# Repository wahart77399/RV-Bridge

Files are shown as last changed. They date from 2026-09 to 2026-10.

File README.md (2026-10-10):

# SmartCoach (aka RV-Bridge): HomeKit to RV-C Adapter 
This is a forked version of Randy Ubillos's RV-Bridge

## Overview
### Credit and Origin
The RV-Bridge was originally developed by Randy Ubillos, you may find the original documentation from him, here at https://github.com/rubillos/RV-Bridge. After reviewing his code, I felt it needed significant work to make it more modular and Object Oriented and less monolithic. I forked from his GitHub and re-architected the design.

## Development and Hardware
Originally, I used Randy’s original hardware and 3D casing. Unfortunately, the ESP32 board he used did not allow me to build all the devices I wanted. So, I researched and found a different board, the ESP32-S3 with CAN and LIN bus connections from SKPang. You can find the board [here](https://copperhilltech.com/esp32s3-can-lin-bus-board/). Once I made that decision, I decided to add more capability, including:
* Captive Portal for setting up Wifi Credentials
* Device Creation from JSON file
* Coach Specification Creation from JSON file
* Auto Discovery of devices
* Web Portal
     * Learning / listening of devices on RVC CAN bus.
     * Coach Spec editing
     * Name assignment and enabling of devices
     * Listening of CAN bus for unassigned devices
     * CAN bus diagnostics
     * Reboot of SmartCoach
     * Automatic email diagnostic and device reports
     * Wipe Wifi Credentials
 
These capabilities add substantial features making it more of a SmartCoach solution and not just a simple bridge.
For email relay setup, see [the guide](cloud/gmail-relay/README.md).
In addition, I've upgraded the library stack to be current with HomeSpan and uses the internal TWAI on the ESP32. Finally, I added regression test suite for the builds.

---
## Sample EVE Home Screens
These screenshots show RV devices in the EVE Home app, including awning, motion, and door-lock controls. The available screens depend on the devices installed in the coach.

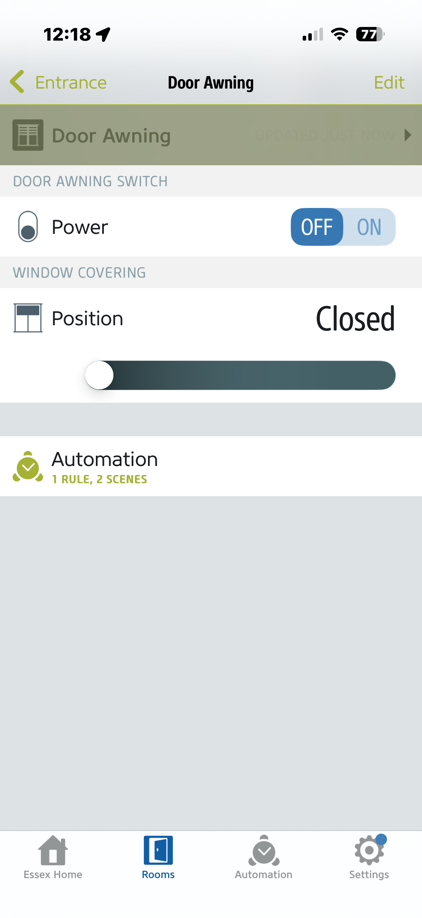
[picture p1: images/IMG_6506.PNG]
Door awning and window covering controls
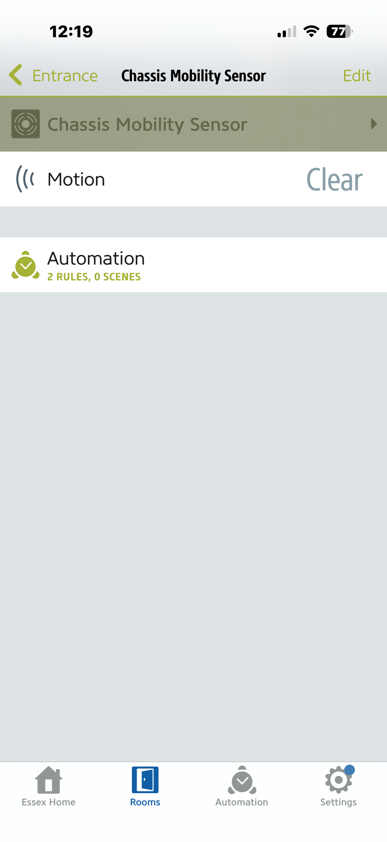
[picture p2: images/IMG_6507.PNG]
Chassis motion sensor status
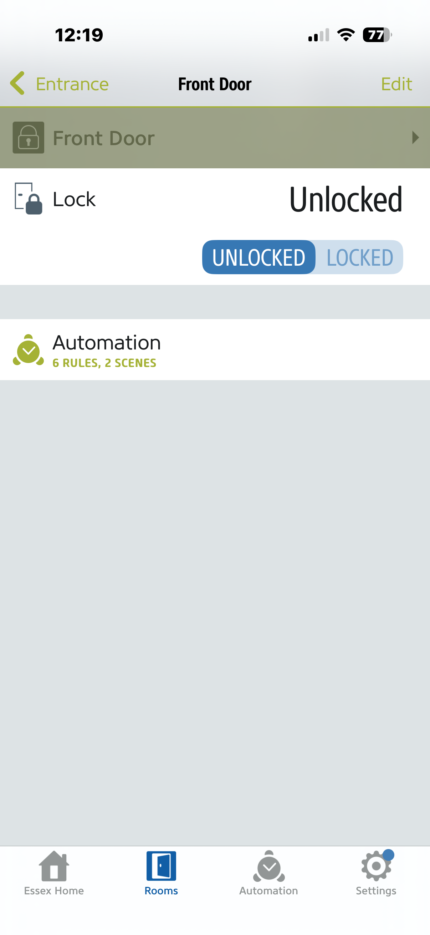
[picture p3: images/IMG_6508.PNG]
Front door lock controls
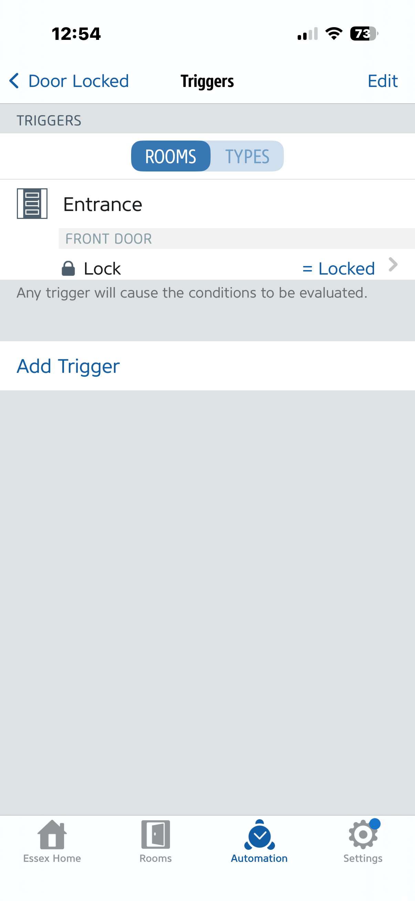
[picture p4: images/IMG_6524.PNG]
          |  
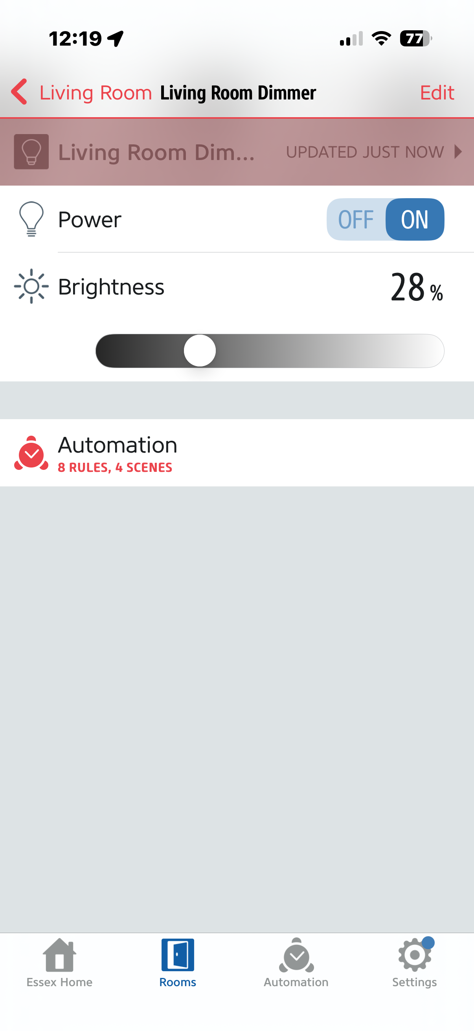
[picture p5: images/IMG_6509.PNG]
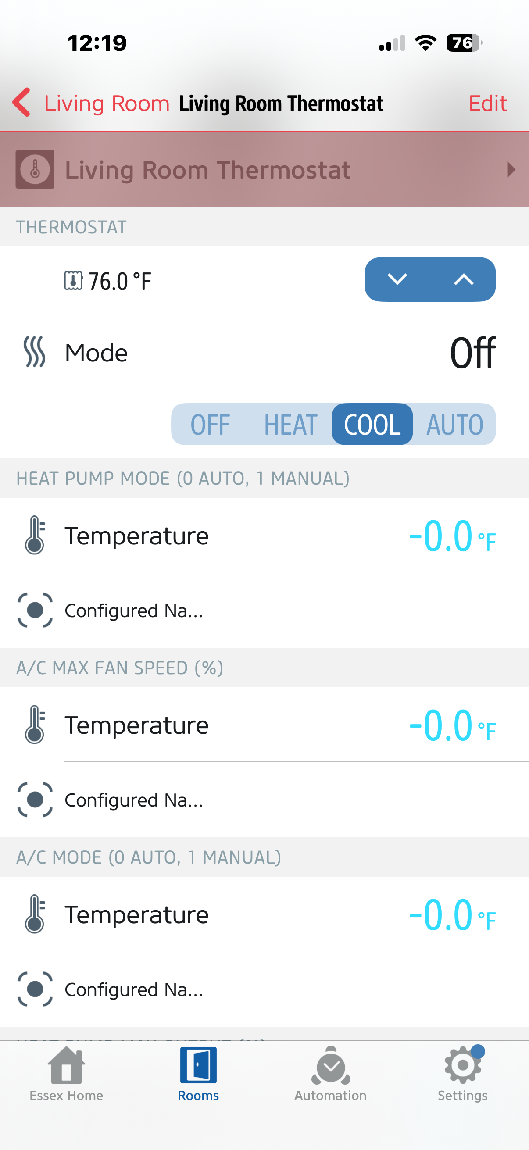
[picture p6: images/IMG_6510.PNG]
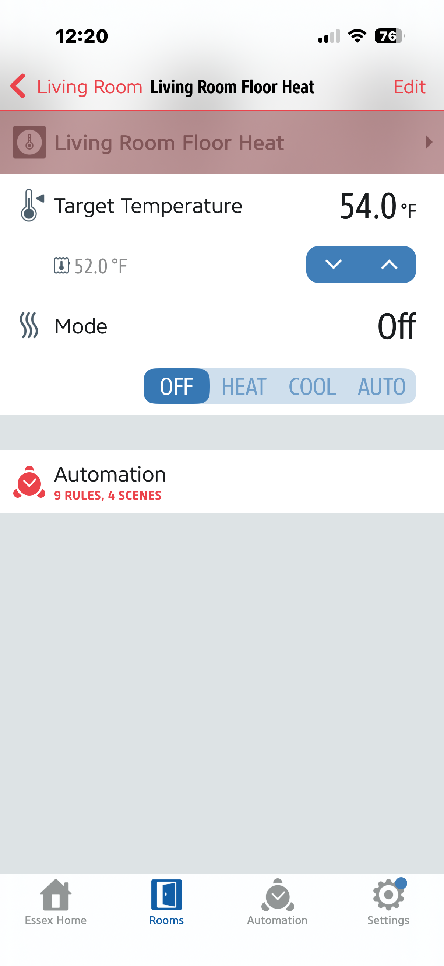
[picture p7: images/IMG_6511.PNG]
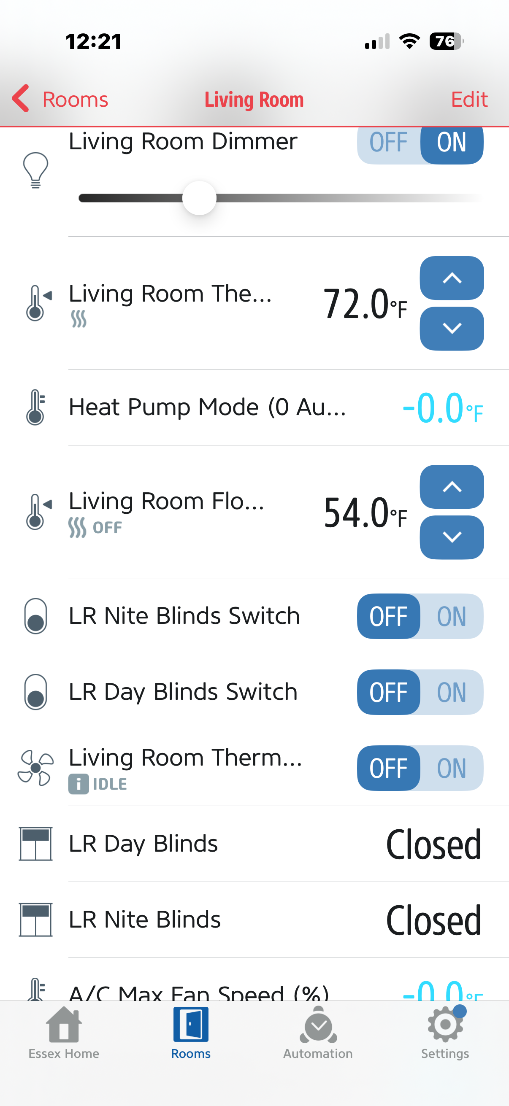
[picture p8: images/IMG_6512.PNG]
          |  

---
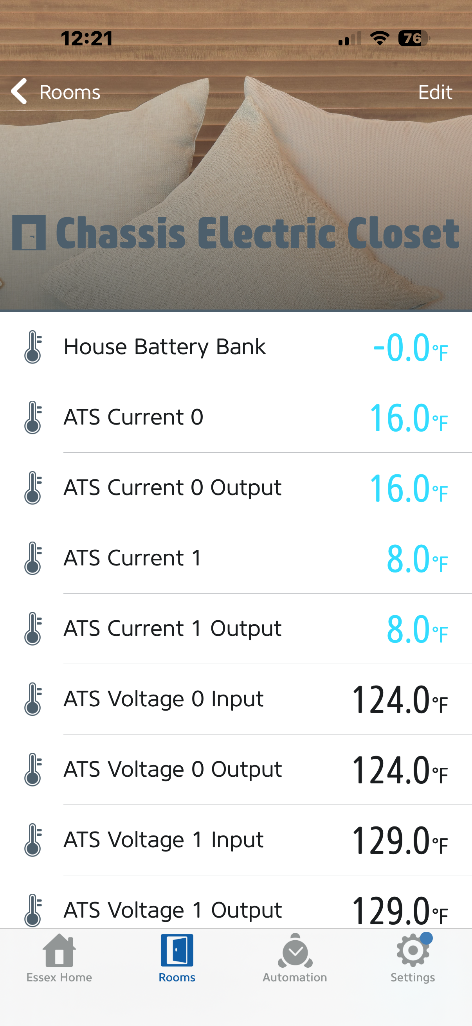
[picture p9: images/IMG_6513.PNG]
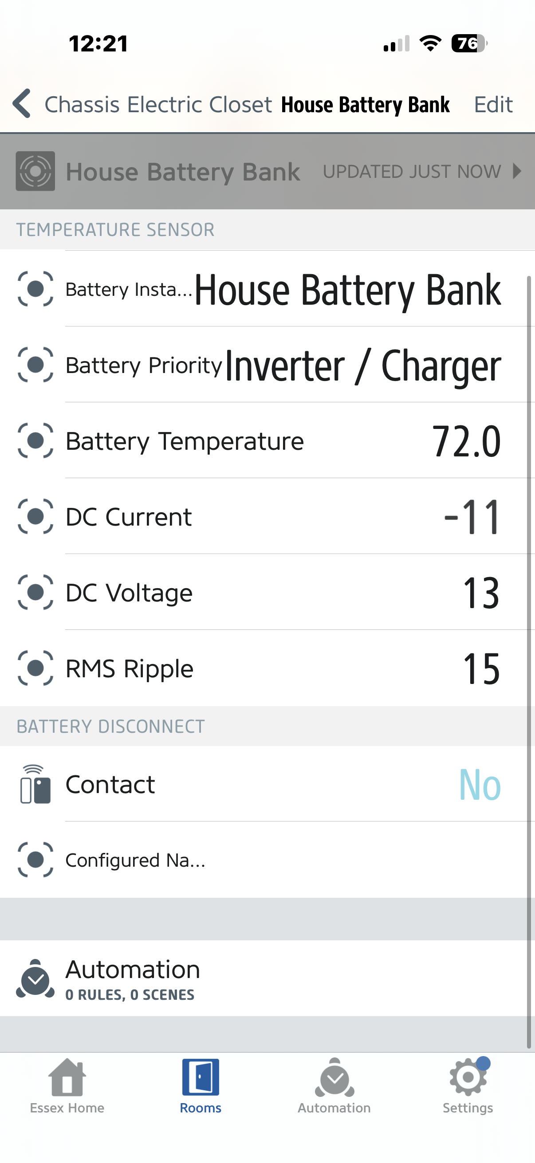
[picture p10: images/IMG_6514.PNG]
    
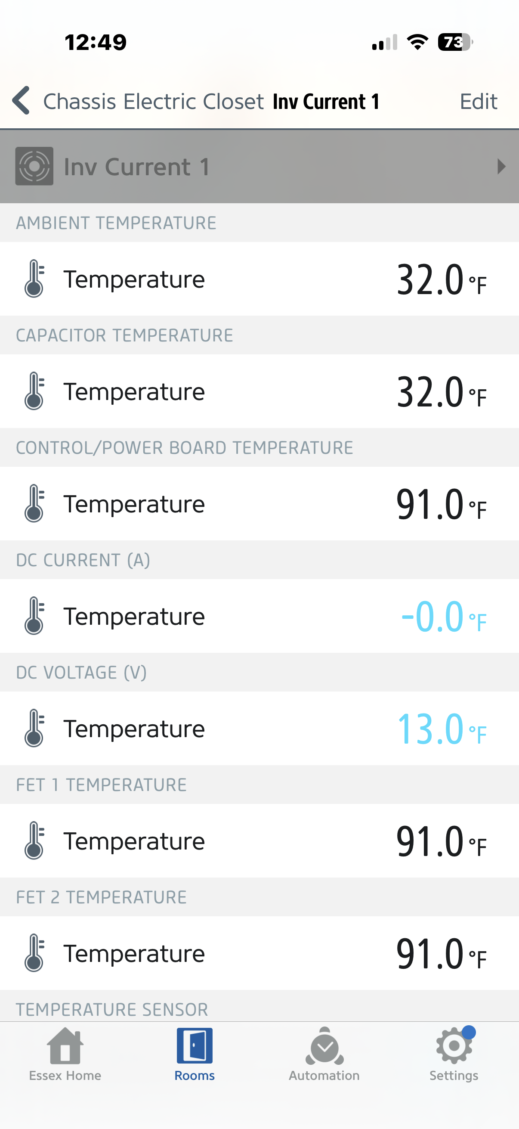
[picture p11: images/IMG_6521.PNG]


---
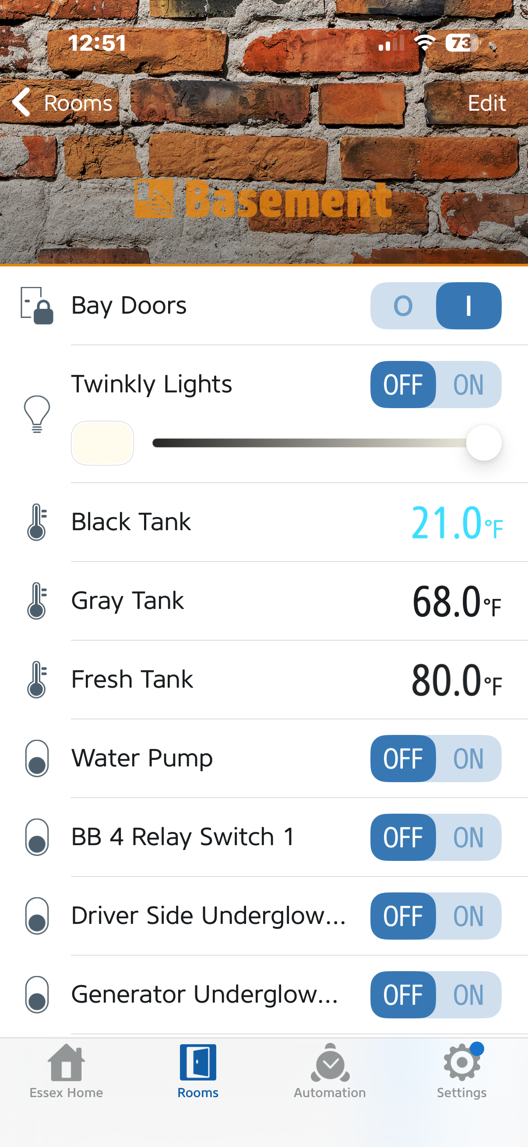
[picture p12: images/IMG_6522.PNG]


---
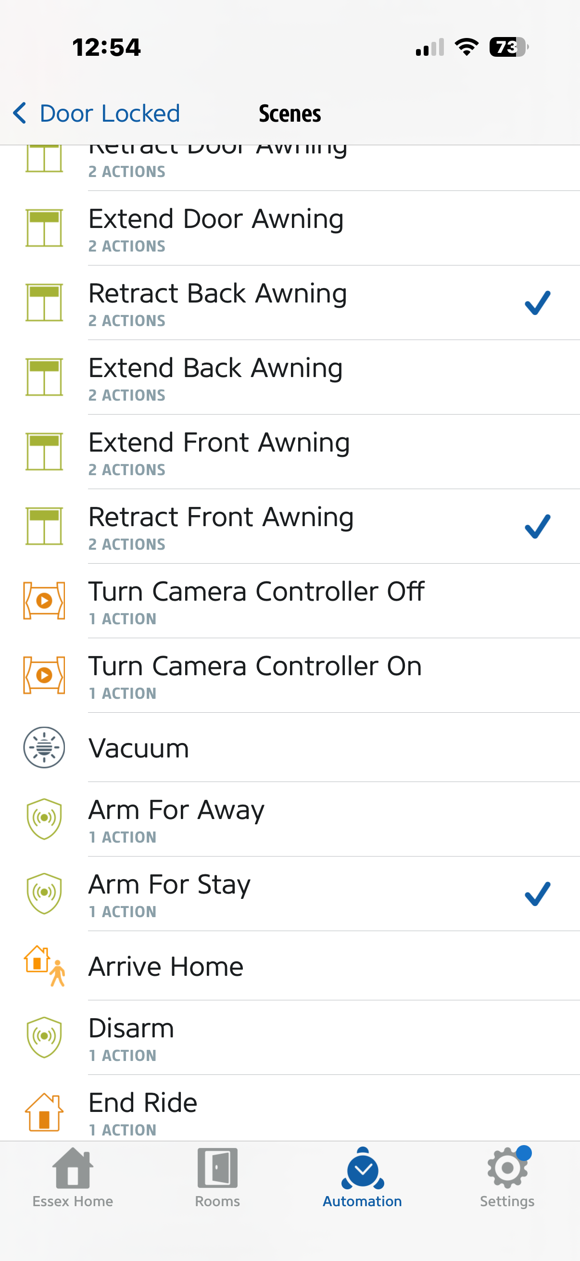
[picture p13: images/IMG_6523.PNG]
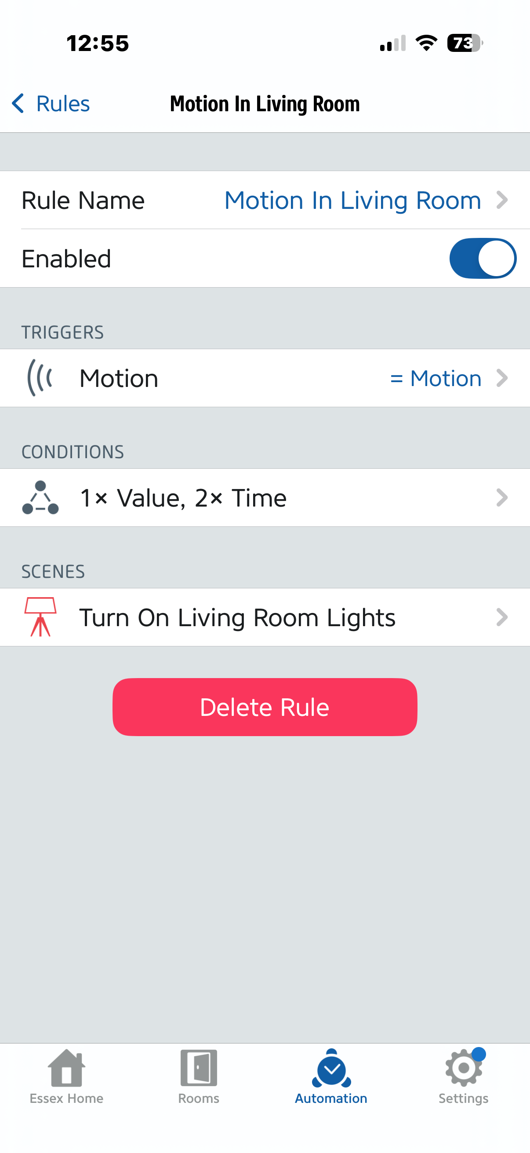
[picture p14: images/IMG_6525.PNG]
  

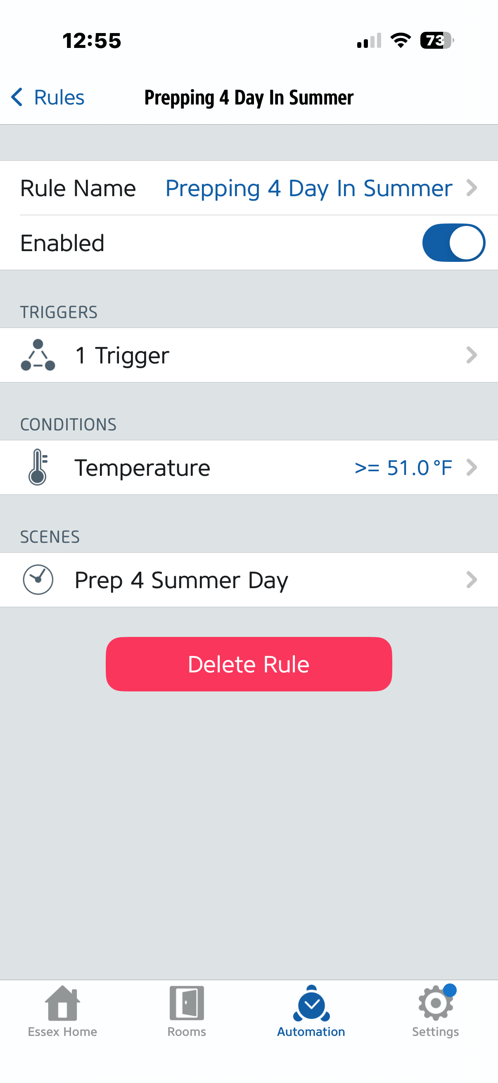
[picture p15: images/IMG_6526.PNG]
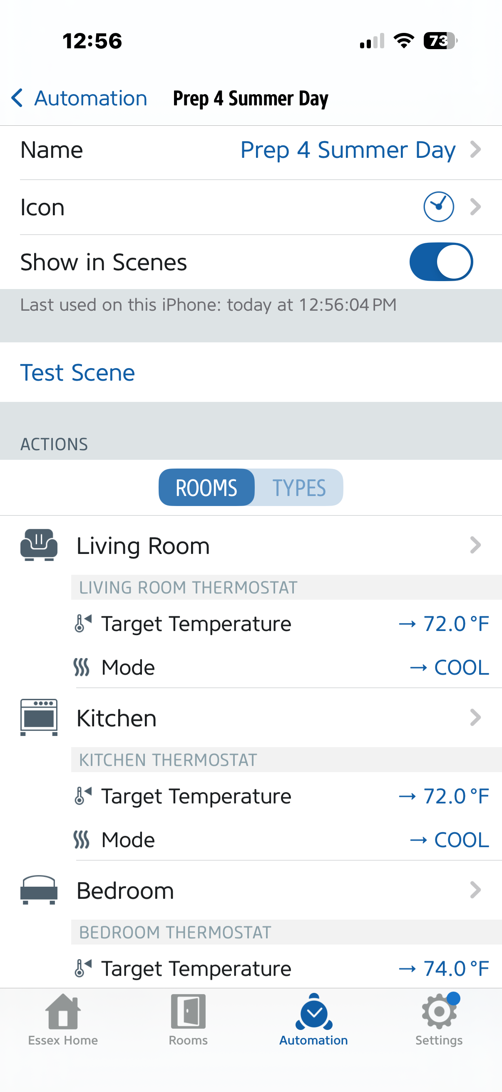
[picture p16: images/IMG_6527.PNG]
  

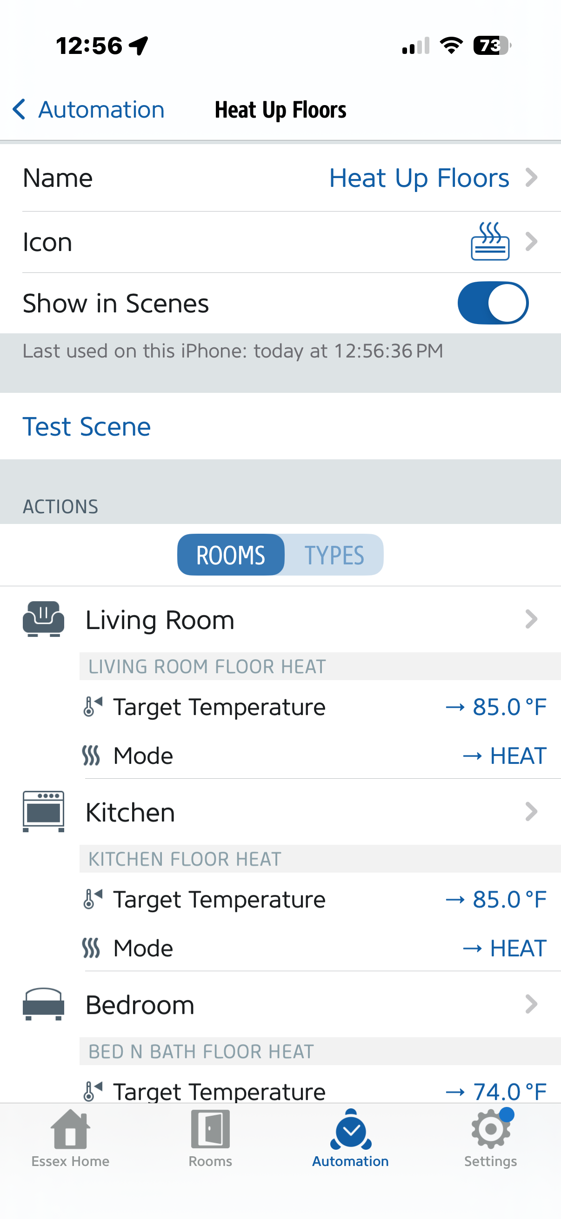
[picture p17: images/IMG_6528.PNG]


## Web Portal
The first screen shows the coach profile and discovered devices.
The upper-right menu provides live Status, Diagnostics, Email Reports, Email setup, and the Privacy Notice. System actions are separated in the menu; Wi-Fi reset and reboot require confirmation. Status refreshes from the bridge's routine status poll without running a discovery scan.

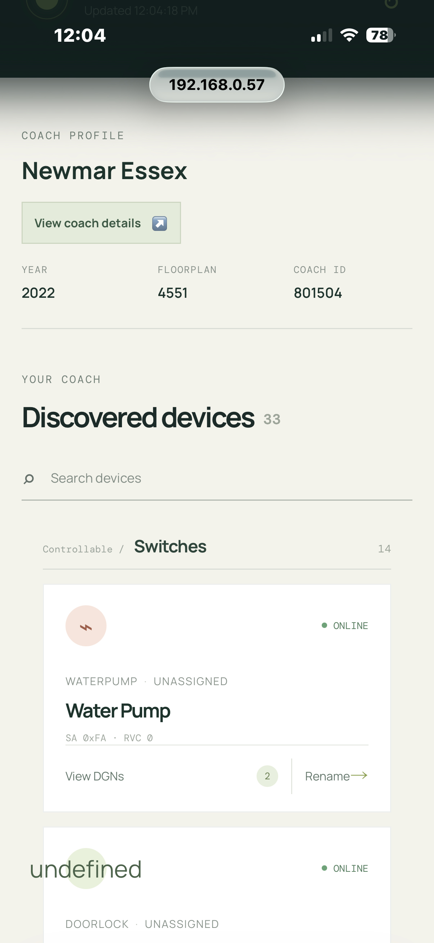
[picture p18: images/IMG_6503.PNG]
Web Portal Top of Page


---
This screenshot, below, shows the coach details when you click on the "View Coach Details" button at the top.

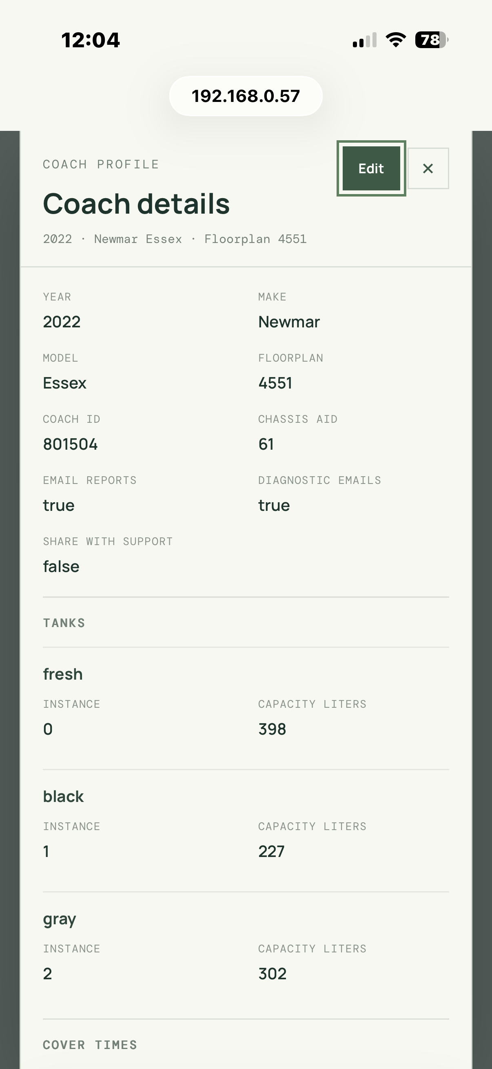
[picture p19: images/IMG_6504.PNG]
Coach Details


---
This Water Pump has been discovered but is still unassigned. Its card shows the two related RV-C messages.

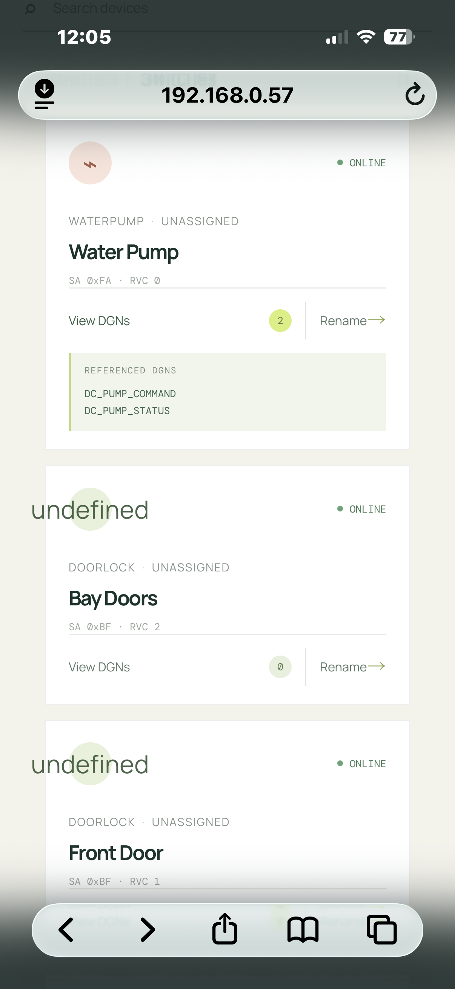
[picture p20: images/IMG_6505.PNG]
Unassigned Water Pump card showing its RV-C messages


---
This screenshot shows an earlier footer layout. The current portal places these tools and system actions in the upper-right menu.

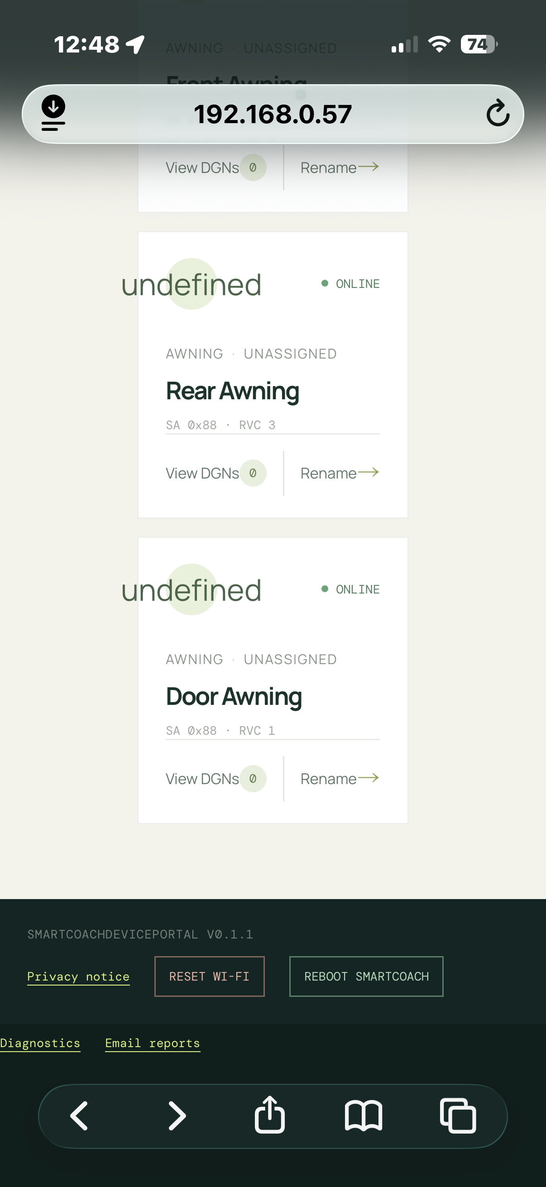
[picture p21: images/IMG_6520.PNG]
Diagnostic Page Bottom


### Diagnostic Portal
The diagnostics page shows bridge health, configured devices, and unmapped CAN traffic.

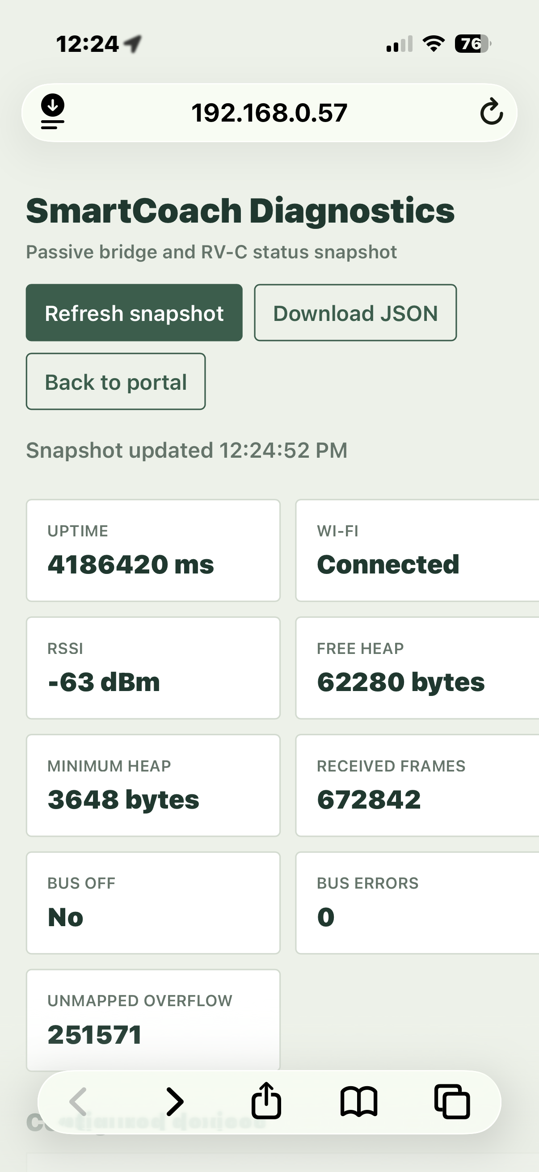
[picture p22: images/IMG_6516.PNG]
Diagnostics Page Top
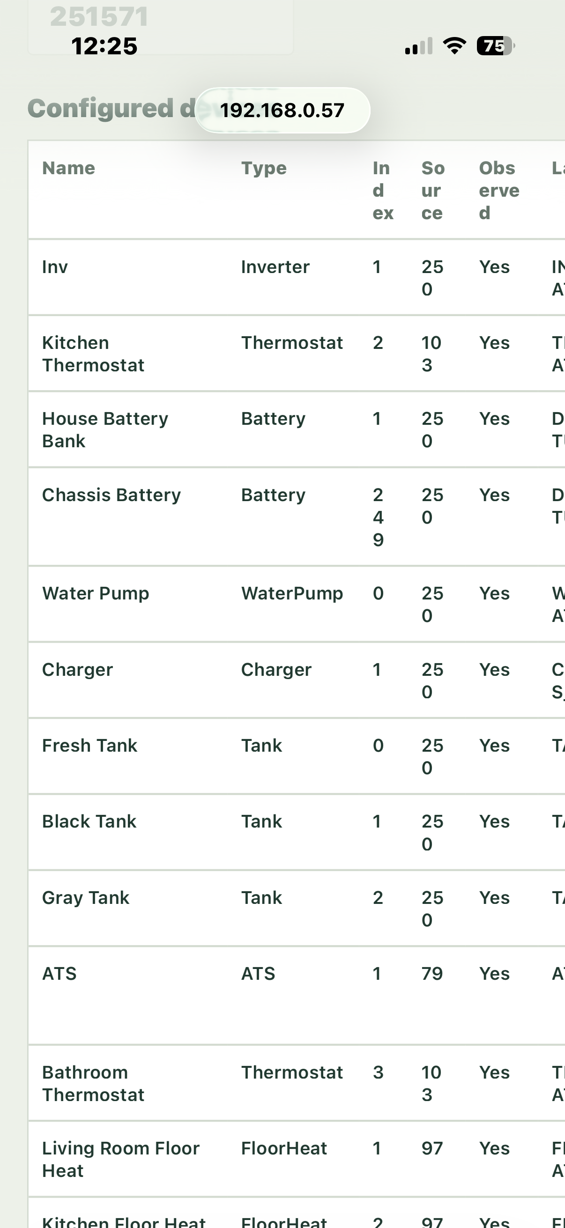
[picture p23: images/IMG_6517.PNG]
Diagnostics Page Showing Configured Device Metrics
   

---
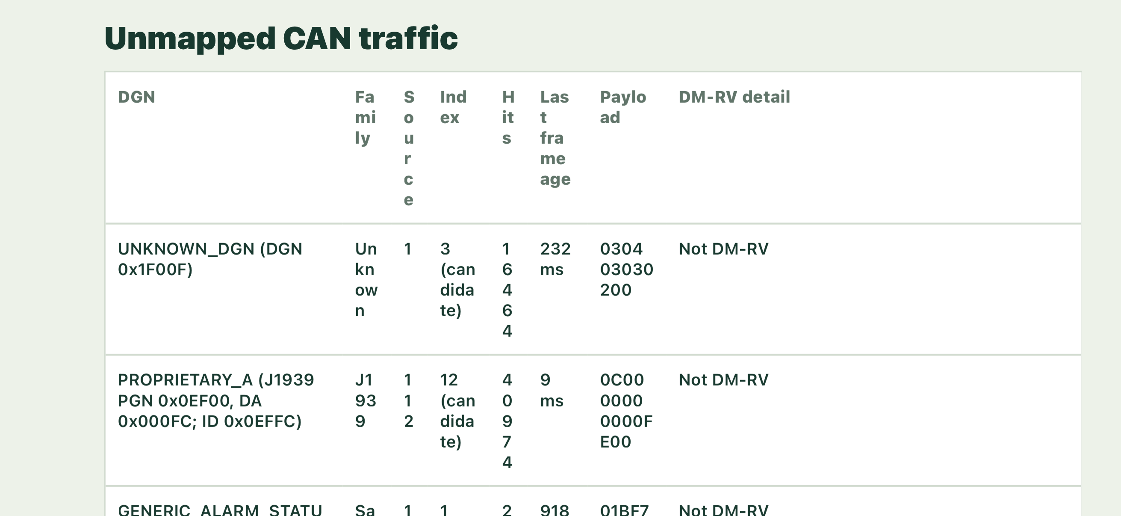
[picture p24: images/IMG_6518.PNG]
Diagnostics table showing unmapped CAN messages

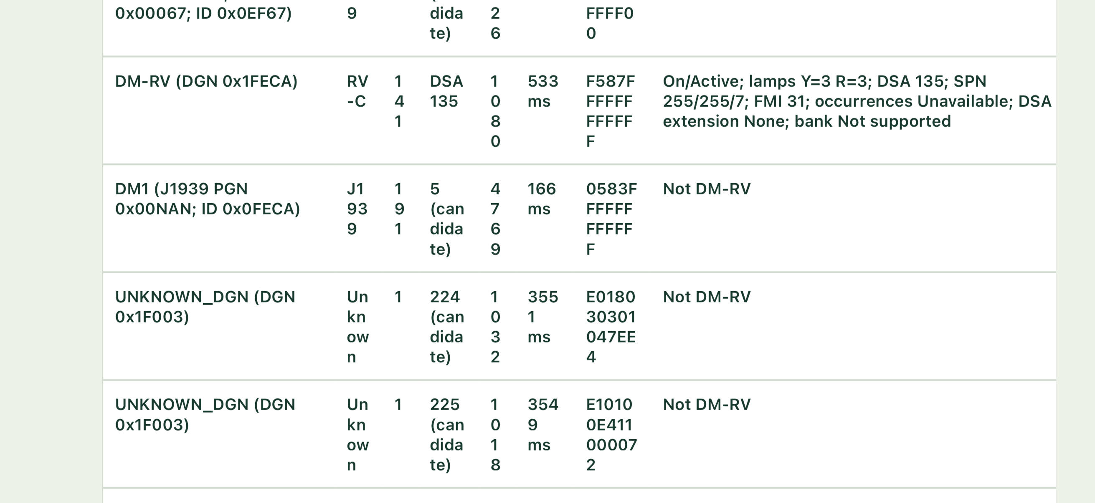
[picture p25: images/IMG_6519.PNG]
Diagnostics table showing decoded DM-RV details


### Email Portal
The email page lets owners choose report options and configure email delivery.

## Captive Portal
The captive portal collects coach Wi-Fi, coach details, and report preferences during setup.
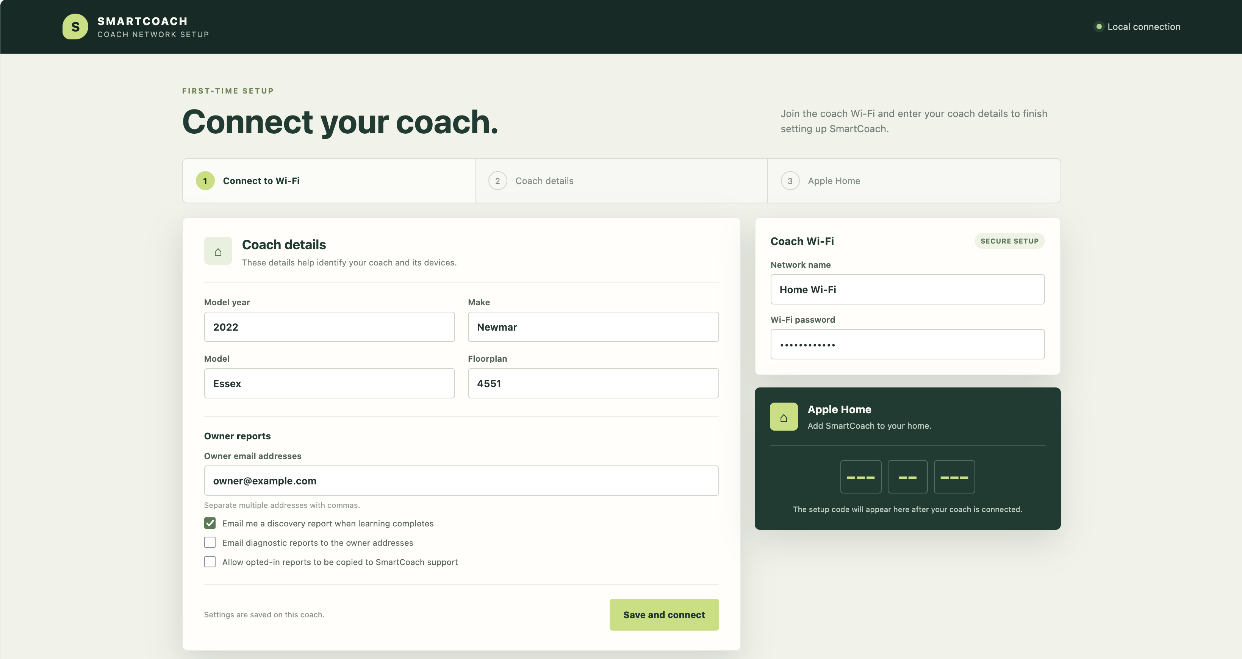
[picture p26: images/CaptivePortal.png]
SmartCoach captive portal setup page


---
## MVC
The architecture relies heavily on the Model View Controller pattern. The Model is the RVC side of the house, the View is the Apple HomeKit and the Controller, if it is not a sensor, is typically a class defined within the View and private to the view. The controller interacts with the model per any changes made within the View (HomeKit). For example, in the ThermostatView, there are 2 controllers, one for the fan and one for the thermostat settings. Why did I make them private within the View Class? I did this to “encapsulate and hide” specific attributes from other non-related classes. This means that the Model, View, and Controller are cohesive and only share what they need to share but not to other un-related classes / objects. 

---
## Libraries
lib_deps =
     elapsedMillis
     homespan/HomeSpan@2.1.8       
     bblanchon/ArduinoJson@^7.2.0
     
---
## Archive
Archive has all of the original code from Randy Ubillos. I created this so that I had ease of access to the original code.

---
## Main
The main.cpp is located directly under the src directory tree. It manages the initialization and start of the code.
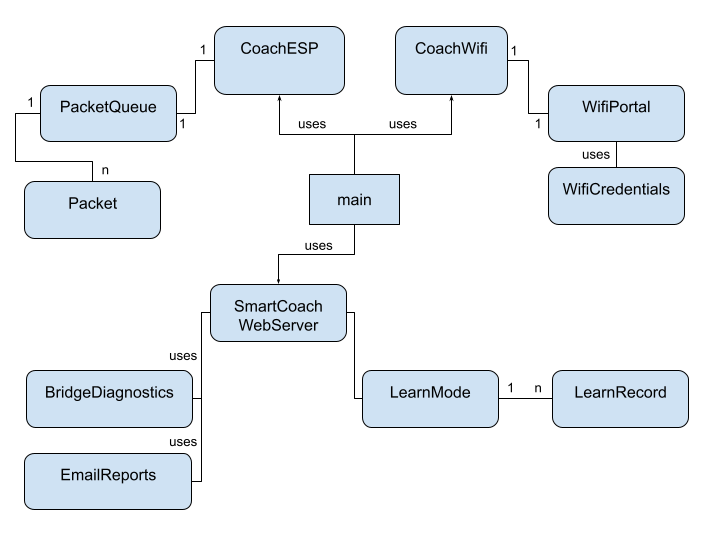
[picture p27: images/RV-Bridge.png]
main associations


---
## Base
The Base folder contains code used across the project. `CoachESP32` manages the board. `CoachWifi` connects to the coach Wi-Fi and starts the setup page when needed. Wi-Fi details are saved on the device, so changing them does not require rebuilding the firmware.

---
## Class Hierarchy
This is a general class hierarchy, meaning Controllable and Sensors are specific devices within the directory structure. Controllable devices include switches, sliders, thermostats, etc. Sensors include power, tanks, and the like. 
DeviceView is a generic term for each View into a specific device. It is the translator of messages to/from HomeKit via the library HomeSpan. In general, when updates occur from HomeKit for controllables, it will translate the message and use the controller to update the model via the ESP32CAN library. Some of the earlier MVC models, like WaterPump, I wrote use update without the controller, that’s a flaw I intended to come back and fix. Sensors do not have a controller since they don’t control anything, they just read values.

NOTE: Since HomeKit does NOT have a unit for volume,  voltage, current or percentage, I use temperature in Fahrenheit to represent those values.

Class Hierarchy

---
## Packets
There are several files in the Packet directory, including:
DGN.h - this contains all the DGN’s defined in the RVC specification
PacketKit.h, Packet.h and Packet.cpp - manages packets sent to the queue on the ESP32. This is also where you will find several print statements commented out where I was discovering what DGNs were communicating on the RVC bus.
PacketQueue.h and PacketQueue.cpp - the packet queue code 
Packets are referenced or used by models and controllers.

---
## Devices
At startup, `DeviceFactory` reads `devices.json` and `coach.json` to create the devices for this coach. You can change many device names and settings in the web portal without rebuilding the firmware.

Saving coach details restarts SmartCoach after the configuration is successfully saved. Use **Apply Device Changes** beside device search to restart and load saved device changes; the button asks for confirmation and does not save unfinished edits.

For an Inverter or Charger whose AC-point instance differs from its device instance, set `"extra": {"acPointInstance": 3}` on that device. Valid AC-point instances are 1 through 13. Without this setting, the bridge uses `rvcIndex` for AC telemetry as before; ordinary status messages still use `rvcIndex`. This maps one AC-point instance per configured device, not multiple independent measurement points.

ATS input/output readings follow the source selected by `ATS_STATUS`. Until a valid source is reported, or when no source is active, the displayed readings remain zero; packets from inactive sources are cached separately.

### RV-C Support Boundaries
For temporary awning interlock diagnosis only, the `AwningDiagnostics` build environment enables `SMARTCOACH_AWNING_PARK_BYPASS`. It bypasses the bridge's park-brake check for awning writes and movement, not shades. Use only under direct supervision with the coach physically immobilized, keep the area clear, and restore `Release` immediately after testing. It must not be shipped to clients. Building does not deploy the bypass; uploading this firmware does. No filesystem upload is needed for this diagnostic test.

The portal's Diagnostics page and downloadable report show named charger operating states, inverter modes, generator states, and ATS source/mode details. Voltage, current, temperature, percentages, and runtime remain numeric. Apple Home's existing tiles are unchanged; custom text is not substituted into numeric HomeKit characteristics.

Generator, inverter, charger, and ATS AC displays consume AC Status Page 1. Pages 2 through 4 (peak readings, power/phase data, and additional qualification/fault data) are not consumed. `CHARGER_STATUS_3` derating telemetry and internal charger DC-bus telemetry are also not consumed.

Battery accessories monitor `DC_SOURCE_STATUS` battery-bank instances, not individual `BATTERY_STATUS` devices. Unsupported bank fields are not displayed. Chassis motion uses speed from `CHASSIS_MOBILITY_STATUS`; the park-brake field remains the command safety gate. `CHASSIS_MOBILITY_STATUS_2` is not displayed. Shade position remains time-estimated because its status message has no absolute position.

Run `perl test/host/run-learning-tests.pl --rvc` for focused production-method payload checks, or omit `--rvc` for the full host suites. These checks and a successful firmware build do not certify live-coach interoperability or full RV-C compliance.

### Generic Device
GenericDevice is model base class and has much of the functionality that all devices use as well as the management of the views. 

### SpanView
SpanView is the base class for all views. Views are HomeKit displays of the specific device. If the device is controllable, then a controller will be embedded privately in the view. Note all devices are ‘friends’ to their views since the view would not exist without the device. Hence, they are cohesive.

### Controllable
All controllable devices (switches and HVAC devices) are located in this directory. 

#### Switches
Switches, including adjustable switches, are located in a sub directory, switches, under controllable. This includes:
* WaterPump
* DoorLock
* LightDevice
* CoverDevices for Awnings and Shades.

#### HVAC
The HVAC devices included are:
* Thermostat: manages and controls the temperature, heat/cool/off setting and the fan settings
* FloorHeat: turns on the floor heat to a desired temperature setting

### Sensors
Sensors are devices that are NOT controlled. I chose not to control the Generator and some of the other devices simply for safety sake. Generator could easily be controlled if you choose to do so.
Non-power sensors include:
* ChassisMobility: detects whether the parking brake is on and if the transmission is in drive/reverse. This is defined as a motion sensor.
* Tanks: tanks are reported in temperature as a percentage. As stated earlier, HomeKit does not have a percent or volume metric to report on. Tanks included are:
   * Fresh Water
   * Gray Tank
   * Black Tank

#### Power
Power is a set of sensors to monitor batteries, inverters, a generator, and automatic transfer switches.
Power devices have an inheritance that is set up to simplify the code; all power devices, except Battery, are inherited from PowerSensor. The following Power devices are available:
* AutomaticTransferSwitch
* Battery
* Generator
* Inverter
* Charger
---
## Other Considerations
In my coach, I’ve added the capability of including Ring devices into the HomeKit. Ring devices are not native to HomeKit, but can be added via a tool similar to my RV-Bridge, Homebridge.org . I use a homebridge on a Orange PI board. I use a Ring plugin to map Ring devices to the Apple Home so, for example, when I lock my door, the Ring alarm is armed and unarmed when the door is unlocked. 

In addition, I use the EVE Home app for any automation, EVE Home is more sophisticated and includes the ability to perform conditional statements where HomeKit does not. In addition, EVE Home is a vendor for motion sensors, security devices, etc.

Finally, I don’t use any RV based networking system like Winegard, I use Unifi’s Ubiquiti. If Ubiquiti was used, you could set up a firewall and link it to Starlink, use an 8 port POE switch, connect the Homebridge solution directly into the switch, and provide a wired connection to an AP on the ceiling and one in the basement for sensors. This would secure the Coach. Also, if clients wanted it, they could opt in to the Unifi Ubiquiti 5G Max which allows for dual sims and Starlink with a dual WAN on the Unifi Ubiquiti UCG-Max or UCG-Ultra. The UCG can be configured to be primary/secondary or load balanced.

---
## Randy's Original Readme

RV-Bridge

---

1. [Features](#features)
2. [Background](#background)
3. [Current Project State](#state)
4. [To-Do](#todo)
5. [Hardware](#hardware)
6. [Wiring](#wiring)
7. [Firmware Setup](#firmware)
8. [Finding Output Numbers](#outputs)
9. [Supported RVs](#rvs)
10. [3D Printing](#3dprint)
11. [Notes and Tips](#notes)
12. [Links](#links)

---
## Features

* Connects to the RV-C network in many modern RVs.
    * RV-C is a subset of CAN-Bus running at 250kbps.
* Uses an ESP32 with a CAN-Bus interface.
* Connects lights, fans, switches, and thermostats to HomeKit.
* Fits inside the RV wiring panel.
* Plugs into an unused CAN-Bus socket for power and data.
* STL files for a 3D printed case are included.

---
## Background

At the start of the pandemic we realized that international travel was going to be off the table for a significant duration. We decided it was time [to see more of the Western US](http://rickandrandy.com/map/index.html?RV) so we bought a class-A motorhome which we call ***The Penguin Express***. We've put [almost 30k miles on it so far](http://rickandrandy.com/?rvlife).

Penguin Express

In addition to a bunch of 3D printed upgrades (we travel with a Prusa MK3S on board), I've done some arduino powered electronics work: a water valve for a reverse osmosis water filter with an LCD control panel, a GPS based clock for the bedroom that knows the exact timezone boundaries so it never needs to be set, and a GPS based altimeter and tire pressure monitor with a 7" color touchscreen for the dash.

The RV's lights, fans, and climate are all controlled through a [Firefly Integrations](https://fireflyint.com) [Vegatouch Spectrum](https://www.vegatouch.com) multiplex system. A 7" LCD panel is used to control everything, in addition to wireless keypads around the RV. There is also a bluetooth module that connects to an iOS app for controlling via an iPhone.

| | |
| --- | --- |
| Firefly Main | Firefly Lights |
| Firefly Climate | Firefly Fans |

It's a great system and works really well for control of the RV devices, but the iOS app is a bit slow to load/connect and can only be used in proximity to the RV. Since we already have an Apple TV onboard driving our TVs which could double as a hub, I've always wondered if there was a way to control it all via HomeKit and the Home app.

Recently I came across some documentation for the bus protocol that's used by the Spectrum system, RV-C, a subset of CAN-Bus, as well as the open source project [CoachProxyOS](https://github.com/linuxkidd/coachproxy-os) that documents getting a Raspberry Pi set up to host a web page for controlling an RV's network using RV-C.

I also recently started playing with [HomeSpan](https://github.com/HomeSpan/HomeSpan), a library for implementing HomeKit accessories on an ESP32 microcontroller, for a HomeKit doorbell project.

RV-Bridge is the result of putting these pieces together.

---
## Current Project State

## v1.0.9 - In progress
* Added option to create two "Thermostats" which show the voltage of the chassis and house batteries as temperature * 10
* Added support for exterior awnings.

## v1.0.0
* Homespan pairing works, devices show up in the Home app.
* CAN-Bus packet receiving works.
* RV-C messages are routed correctly to the HomeKit tiles.
* The correct RV-C packets are being sent over the bus based on changes made in the Home app for lights, switches, and fans.
* The RV devices respond correctly.
* Lights, switches, and fans are complete.
* Temperature readings from thermostats are reflected in the Home app.
* Thermostat control is complete.

### v3.0.7b Validation
* Diagnostics now fail closed when heap headroom is insufficient. Twenty repeated low-heap requests returned HTTP 503 without a panic or reboot.
* A development firmware update/reboot preserved `chassisAid` and accessory AIDs; the existing HomeKit pairing remained intact and did not require re-pairing.

---
## To-Do

* **Tech debt (awning/chassis refinement, deferred until owner returns from visiting family):** Investigate the intermittent park-brake-unavailable event that rejected awning writes in Eve. Preserve the normal safety interlock and client pairing/accessory identities. Capture unavailable-state packets with source addresses and timestamps, check decoding/routing/startup/freshness behavior, and verify accepted/rejected writes and scene behavior across brake states. See the analysis below; a permanent decoder fix has not yet been established.
* **Remaining HomeKit validation:** The v3.0.6b development upload reported HomeSpan database validation with zero warnings and zero errors. A later development firmware update/reboot retained accessory AIDs and the existing pairing. Still check existing Home/Eve displays for Charger State, AutoFill Last Operation, and Generator Engine Status; client update and failure paths must preserve AIDs, IIDs, and pairings without re-pairing.
* **Remaining stability verification:** Routine portal polling reuses a cached discovery snapshot; `/discovery` is fetched on initial load and explicit Scan, while `/status` keeps learning state live. The v3.0.6b diagnostics stream uses fixed-length, counted writes. Five consecutive live diagnostics reports (about 24.5 KB each) parsed successfully; status heap stayed between 63,480 and 63,508 bytes across those requests with zero queue drops. The v3.0.7b low-heap guard also returned HTTP 503 for 20 repeated requests without a panic or reboot. Longer mixed-load monitoring is still needed to characterize transient headroom under startup, scans, diagnostics, and HomeKit activity.
* **Tech debt (client-release requirement):** Provide a portal-update process that automatically preserves saved coach settings, device configuration, accessory IDs (`aid` and `chassisAid`), and HomeKit pairings. A single development firmware update/reboot preserved AIDs and pairing, but portal/filesystem update and failure paths remain unverified. Filesystem/portal updates must not replace client settings with bundled defaults. Manual configuration backups are a development workaround, not an acceptable client-update requirement.
* **Tech debt (soon, deferred until owner is ready):** Replace numeric power-state tiles in Apple Home (for example, Charger State `6`) with understandable named status indicators such as "Float Charging." Review other power-state codes too. Apple Home cannot display arbitrary status strings. HomeKit service changes and re-pairing are acceptable during development only. Client releases must preserve existing pairings and accessory identities without requiring re-pairing. Readable status text already exists in portal diagnostics.
* Some RVs have AC units that can work as a heat pump; only the AC portion of these units is currently handled. (Ours only has a furnace so I don't currently have a way to implement this.)

### Awning And Chassis Analysis
* Eve reported read/write failure and reverted the awning switch to Off while diagnostics reported **Park brake unavailable**. The guard rejects released, unknown, reserved, or unreceived brake status; physical parking alone does not establish what the bridge received.
* The temporary `AwningDiagnostics` bypass allowed extension, isolating the rejection to the park-brake guard. The bypass is now disabled on the live bridge: guarded `Release` was restored. Do not ship or retain the bypass as a client fix.
* Passive instrumentation captured `CHASSIS_MOBILITY_STATUS` (`0x1FFF4`) from source address 148: `00 00 00 00 FD FF 7D 7D`. Byte 4 is `FD`, and bits 0-1 are `01` (park brake engaged). Fresh observations continued to report engaged. The earlier unavailable payload was not captured, so its cause remains unproven.
* A separate host-reproduced HomeKit conflict was fixed: an Out/In callback no longer calls `setVal()` on an already-pending `TargetPosition` write. Standalone On still requests fully out; Off requests fully in. An explicit pending position takes precedence in a combined write. This defect is not proven to have caused the original live brake-status failure.
* After guarded Release deployment, the owner verified front-awning extension through Eve and the **Retract Front Awning** scene. Both directions worked with the safety guard enabled; other awnings and longer-term stability still need verification.
* On return, capture the missing failure evidence and add bounded transition history/rejection reasons if needed. Test engaged/released/unavailable/stale/startup status, conflicting sources, standalone switches, explicit positions, combined writes, and scenes. Never infer a safe park state solely from zero speed or unknown brake bits.

---
## Hardware

Uses an ESP32 with a CAN-Bus interface, either as separate components, or more easily, this board I found from [skpang.co.uk](https://www.skpang.co.uk):

The photo shows the ESP32 board used for the bridge.

ESP32 Module

In the U.S. it's available on the CopperHillTech Website:<br>
[ESP32 with WiFi, Bluetooth Classic, BLE, CAN Bus Module](https://copperhilltech.com/esp32-wifi-bluetooth-classic-ble-can-bus-module/)

This board has everything needed, including a regulator for powering the device off of the 12V provided by the RV-C connector.

---
## Wiring

The connector used by the Firefly system is a ***3M 37104-A165-00E MB*** which can be sourced from [Digikey](https://www.digikey.com/en/products/detail/3m/37104-A165-00E%2520MB/1855697)

Insert four 24AWG wires into the Can-Bus connector (I used silicone covered wire as they are much more flexible) and compress to make the connections. Twist the data and power pairs together and screw them into the terminal block on the CAN-Bus interface on the ESP32.

The CAN-Bus connector plugs into one of the available sockets inside the system wiring panel.

The photos below show the cable, connector wiring, the coach wiring panel, and the Home app after setup.

|  |  |
| :---: | :---: |
| <br>Cable Wiring |Can-Bus Connector Wiring |
| G7 Panel | Home App |

---
## Firmware Setup

- The project is set up for compilation with PlatformIO.
    * I use it via Microsoft's Visual Studio Code.
- Pretty sure you could also use the Arduino IDE. You'd need to install the following libraries:
    * elapsedMillis
    * miwagner/ESP32CAN
    * homespan/HomeSpan
- `config.h`
    * Duplicate `config-sample.h` to `config.h`. (Do not check this file into git, it will have your wifi passowrd in it)
    * Enter Wifi SSID and password for your RV network.
    * Include a definition file for your RV devices (see `Miramar_2020_3202.h` for an example).
        * Each switch has:
            * Output number.
            * Type: Lamp, DimmableLamp, or Switch.
            * Name.
        * Each fan has:
            * Output number for fan power.
            * Output number for up - optional, -1 if not used.
            * Output number for down - optional, -1 if not used.
            * Name.
        * Each thermostat has:
            * ID number, typically 0 based.
            * Output number for the A/C compressor.
            * Output number for low fan.
            * Output number for high fan.
            * Output number for furnace - optional, -1 if not present.
            * Name.
        * Each awning has:
            * Output number for extend.
            * Output number for retract.
            * Time (in ms) that the awning takes to get to the "unroll" portion.
            * Time (in ms) that the awning takes to "unroll" at the end. Set to 0 if not applicable.
            * Time (in ms) that the awning takes to get from the "roll" portion to fully retracted.
            * Time (in ms) that the awning takes to "roll" at the beginning. Set to 0 if not applicable.
            * Name.
        * See [Finding Output Numbers](#outputs) below for details on output numbers.
    * Uncomment `#define CREATE_BATTERIES` to create "Thermostats" for the house and chassis batteries.
        * The "thermostat" will show the current battery voltage times 10 as temperature.
            * Homekit does not currently have a way to display voltages, so this is my hack to be able to see this very useful information.
        * You will likely want to turn off "Include in Home Summaries" in the Status setting for these "thermostats".
        * When in screen "rearrange" mode you can tap on a thermostat and choose to show it in a smaller sized tile.
- Flashing
    * If you are using an ESP32 with a USB-C connector and flashing from a Mac, you may need to connect it via a USB hub due to some timing weirdness around resetting the ESP32 into boot mode. I use a USB-C to 4 port USB-A hub with a USB-A to USB-C cable.
- Startup
    * Connect to the ESP32 via the Serial Monitor.
    * You should see a bunch of startup logging.
    * Then a message about being connected to Wifi and not being paired.
    * HomeSpan provides a command line interface that you can access through the Serial Monitor. Type '?' to see the available comands.
- Pairing
    * Be on the same wifi network and in close proximity to the ESP32.
    * In the Home app choose "Add Accessory".
    * Point the camera at this image:
    <br><br>
    Pairing Code
    <br><br>
    * Tap on `RV-Bridge`.
    * Accept that this is an "unsupported" device.
    * Add the bridge and all of your accessories, choosing appropriate rooms and names for them.
    * Done!
- The status LED will flash based on what the bridge is doing:
    * 🟢 Green every 2 seconds as a heartbeat indicator.
    * 🔴 Red when CAN-Bus packets are sent.
    * 🔵 Blue when HomeKit messages are received.

---
## Finding Output Numbers

The whole multiplex system connects back to a panel with outputs for all of the lights and fans. Each of these outputs has a unique number which may be printed on the panel's cover, and should also be found on a Network Diagnostic screen on the main LCD control screen.

G7 Outputs

*** ***USE EXTREME CAUTION WHEN ENTERING OUTPUT NUMBERS. THERE ARE OUTPUTS FOR THE RV SLIDES AND THINGS LIKE MOVEABLE BUNKS. YOU DO NOT WANT TO MISTAKENLY PICK ONE OF THOSE OUTPUTS FOR A LIGHT OR FAN!*** ***

---
## Supported RV's

Currently the project includes definition files for these RVs in the `RV` folder:

[Miramar_2020_3202.h](/src/RV/Miramar_2020_3202.h) - 2020 Thor Miramar 32.2<br>
[Aria_2019_3901.h](/src/RV/Aria_2019_3901.h) - 2019 Thor Aria 39.1<br>
[Tiffin_2019_34PA.h](/src/RV/Tiffin_2019_34PA.h) - 2019 Tiffin Open Road 34PA<br>
[Jayco_2023_Terrain.h](/src/RV/Jayco_2023_Terrain.h) - 2023 Jayco Terrain 19Y

(Additional definition files are welcome!)

---
## 3D Printing

- A case will keep the microcontroller isolated from any exposed contacts inside the wiring panel.
- STL Files are in the `3D` folder:
    * [RV-Bridge_Box_Bottom.stl](/3D/RV-Bridge_Box_Bottom.stl)
    * [RV-Bridge_Box_Top.stl](/3D/RV-Bridge_Box_Top.stl)
- Slicer
    * I used Prusa Slicer 2.5.0
- Build Plate
    * A textured build plate give a nice surface finish for the top and bottom of the box.
- Filament
    * PETG - handles heat better than PLA and sticks to a textured build plate much better than PLA.
- Settings to adjust:
    * `Layer Height`: 0.3mm (faster printing)
    * `Extrusion Width`: 0.55mm (eliminates tiny infill strips in the walls).
    * `Perimeter Transitioning Threshold Angle`: 20 (keeps the lettering connected).
    * `Bridging Angle`: 180º (bridging in the layer above the lettering should be parallel to the baseline of the text.)

---
## Notes and Tips

- If the bridge seems to become unresponsive at some point, verify that the controlling device is on the RV's Wifi and not some other weak Wifi.
- If the bridge doesn't seem available for pairing, it may already think it's paired. Try using the H command via the cli in the serial monitor, then reflash the ESP32 and try again.
- If pairing fails, it seems that sometimes HomeKit gets fussy about a device changing it's properties too much and refuses to pair. You can change the MAC address of the wifi interface on the ESP32 by defining `OVERRIDE_MAC_ADDRESS` in `config.h` and re-flashing. Anecdotal evidence suggests that this can help.

---
## Links:

- [Apple's HomeKit Accessory Protocol Specification Release R2 (HAP-R2)](https://developer.apple.com/homekit/specification/)
    * For some reason this link appears to be broken on the Apple side at the moment... with _just a tiny bit_ of hunting on the internet you can find it 😉
- [RV-C Organization](http://www.rv-c.com)
- [RV-C Spec 2022-12-01](http://www.rv-c.com/sites/rv-c.com/files/RV-C%20Protocol%20FullLayer-12-01-22.pdf)
- [SK Pang Electronics](https://www.skpang.co.uk)
- [Schematic for the ESP32 CAN-Bus Board above](https://cdn.shopify.com/s/files/1/0563/2029/5107/files/ESP32_CAN_rev_B.pdf?v=1620032162)

---

Copyright © 2023-2024 [Randy Ubillos](http://rickandrandy.com)

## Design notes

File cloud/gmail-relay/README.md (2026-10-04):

# Gmail Relay

This Google Apps Script web app sends SmartCoach reports through the Gmail account that authorizes the script. Gmail credentials never go on the ESP32. The web app requires a per-coach bearer token in the JSON body, checks recipients against a per-coach allowlist, requires the category-specific consent bit, honors support sharing separately, limits a coach to three send attempts per UTC day, and deduplicates successful request IDs for six hours.

Apps Script web apps return JSON bodies but do not let `doPost` select an HTTP status code. Clients must inspect the response's `ok` and `code` fields. A response with `code: "delivery_uncertain"` must not be retried automatically because Gmail may already have accepted the message.

## Current Beta Deployment

Apps Script web app URL: `https://script.google.com/macros/s/AKfycbybuF3VJumdiLCmmu7gZgZvpZQ8uzfkqjxzM2ixF9drJ8Zk7UGCXgdsC7jP20nxdnC5LQ/exec`

SmartCoach email settings page: `http://<current-bridge-ip>:8080/email`

## Setup

1. Create a standalone project at [script.google.com](https://script.google.com) and add `Code.gs` and `RelayTests.gs` from this folder.
2. Run `runRelayTests` from the Apps Script editor. It should return `10/10 relay tests passed` without sending email.
3. Generate a unique 32-byte token for each coach and encode it as exactly 64 hexadecimal characters. Keep the raw token for the device configuration. Temporarily set the script property `TOKEN_TO_HASH` to that token, run `hashTokenForRegistry`, and copy the logged SHA-256 digest. The helper deletes `TOKEN_TO_HASH` after hashing.
4. Set the script property `DEVICE_REGISTRY_JSON` to an object keyed by the exact `coachId`. Each entry has `tokenSha256`, `ownerEmails` (the recipient allowlist), and `supportAllowed` (normally `false`). Example:

   ```json
   {"coach-123":{"tokenSha256":"64-character-sha256-hex","ownerEmails":["owner@example.com"],"supportAllowed":false}}
   ```

5. Set `SUPPORT_EMAIL` only if support delivery is used. Both the device's `shareWithSupport` consent and the registration's `supportAllowed: true` are required for a support copy.
6. Deploy as a web app that executes as your Google account and is accessible to anyone. The URL is public, but requests without a registered coach token are rejected. Keep the token out of source control, screenshots, and chat.

## Request Contract

The POST body is the staged report envelope plus a top-level `relayToken`. Discovery messages require `ownerEmailConsent: true`; diagnostics require `diagnosticEmailConsent: true`. The relay only sends to registered owner addresses. It never places the relay token in the email body.

Email routes and transport are included in normal `Release`; `EmailBeta` remains as a compatible alias. Sending still requires owner consent, registered owner addresses, and a per-coach relay token. Opted-in learning completion stages and attempts the discovery report once. A failed send stays in the outbox. The portal can edit the owner recipient allowlist, stage a completed learning report or, if none exists, an explicitly labeled snapshot of the current `devices.json`, and manually retry a pending report. Relay URL and token are configured in the portal; the token is stored in NVS, never returned by the device, and is not included in `coach.json` or the email body.

Build the standard firmware with `platformio run --environment Release`. `DiagnosticsBeta` remains as a compatible alias; diagnostics collection and manual download are included in all environments. The relay has completed a live owner-only beta send; additional coaches still need distinct registry entries and relay tokens.

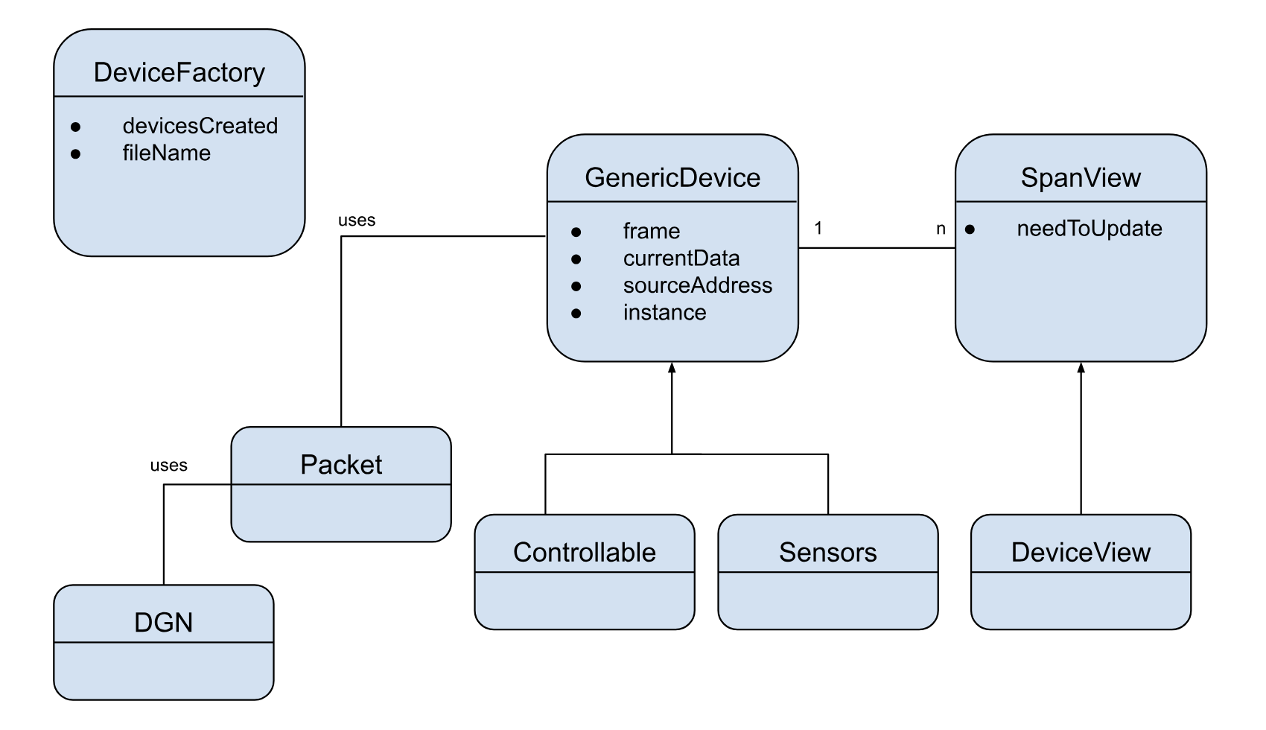
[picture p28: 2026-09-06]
images/Class Hierarchy.png

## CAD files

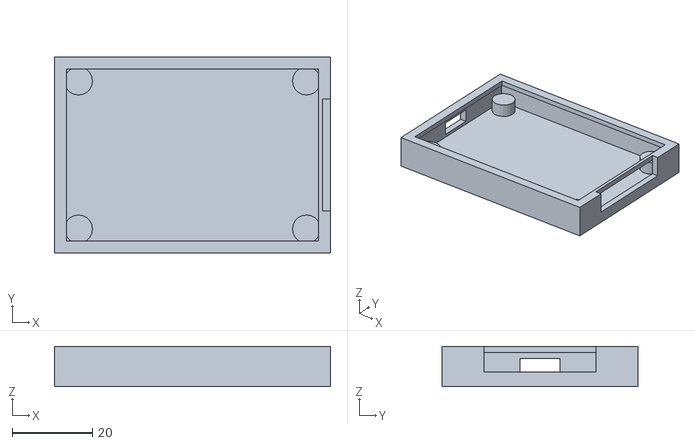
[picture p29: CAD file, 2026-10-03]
3D/ESP32S3_CAN_LIN_Box_Bottom.stl
69.0 x 49.0 x 10.0

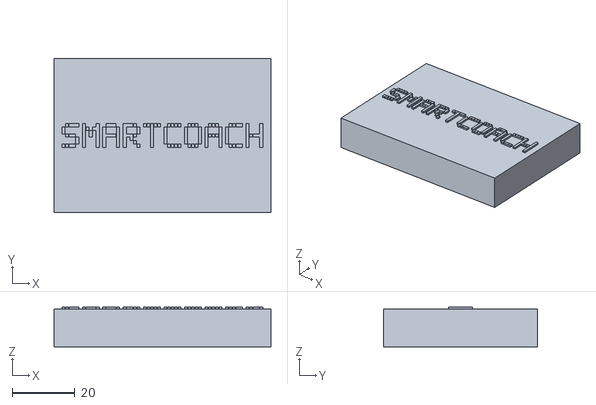
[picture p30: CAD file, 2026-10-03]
3D/ESP32S3_CAN_SmartCoach-Top.stl
69.0 x 49.0 x 12.6

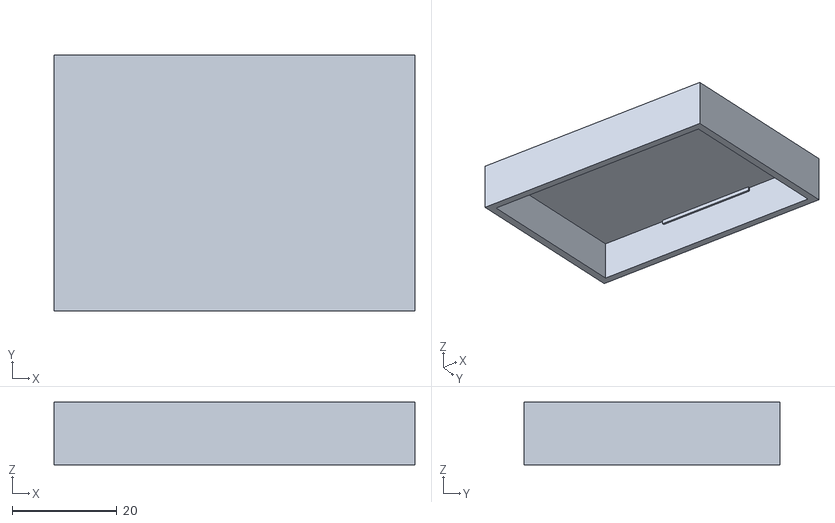
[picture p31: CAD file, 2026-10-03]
3D/ESP32S3_CAN_LIN_Box_Top.stl
69.0 x 49.0 x 12.0

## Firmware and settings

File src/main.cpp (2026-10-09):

/*********************************************************************************
 *  MIT License
 *  
 *  Copyright (c) 2023 Randy Ubillos
 *  
 *  https://github.com/rubillos/RV-Bridge
 *  
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
 ********************************************************************************/
 
////////////////////////////////////////////////////////////////
//                                                            //
//    RV-Bridge: A HomeKit to RV-C interface for the ESP32    //
//                                                            //
////////////////////////////////////////////////////////////////

#include "Arduino.h"

#define CUSTOM_CHAR_HEADER  // this must be done prior to #include of HomeSpan call anywhere.
// #include "CAN_config.h"
#include "CanFrameTypes.h"

#include <CoachWifi.h>
#include <CoachESP32.h>
#include <SmartCoachWeb.h>
#include <WifiCredentials.h>
#include <DeviceFactory.h>
#include <LearnMode.h>
#include <Packet.h>
#include <PacketQueue.h>
#include <debug.h>

CAN_device_t CAN_cfg;

void setup() {
	RV_PRINTF("setup start\n");
#if defined(SMARTCOACH_AWNING_PARK_BYPASS) && SMARTCOACH_AWNING_PARK_BYPASS
    Serial.println("WARNING: DIAGNOSTIC BUILD - AWNING PARK-BRAKE INTERLOCK BYPASSED. Restore Release after testing.");
#endif
	pinMode(LED_BUILTIN, OUTPUT);

	CoachESP32* coachESP32 = CoachESP32::getInstance(&CAN_cfg);
	if (coachESP32 == nullptr) {
		RV_PRINTF("ERROR: CoachESP32 init failed\n");
		return;
	}
	RV_PRINTF("CoachESP32 instance created/obtained\n");
	coachESP32->initialize();

	CoachWifi* coachWifi = CoachWifi::getInstance();
	if (coachWifi == nullptr) {
		RV_PRINTF("ERROR: CoachWifi init failed\n");
		return;
	}
	RV_PRINTF("CoachWifi instance created/obtained\n");
	coachWifi->initialize();
	if (CoachWifi::isProvisioning()) {
        RV_PRINTF("setup: Wi-Fi provisioning - devices and CAN not started\n");
        return;
    }

	SmartCoachWebServer::instance().begin();

	RV_PRINTF("setup: DeviceFactory getting instance\n");
	DeviceFactory* factory = DeviceFactory::getInstance();
	if (factory == nullptr) {
		RV_PRINTF("ERROR: DeviceFactory init failed\n");
		return;
	}
	LearnMode::begin();

	RV_PRINTF("%u: Init complete.\n", (uint32_t)millis());
	// Packet dump on while gathering raw RV-C instance data
	Packet::setPacketPrintMode(packetPrintYes);
	Packet::initialize();
	RV_PRINTF("setup complete\n");
}

void loop() {
	PacketQueue::adjustTimingOfPacketRecieve();
	CoachWifi::pollSpan();
	if (!CoachWifi::isProvisioning()) {
		CoachESP32::pollESP32();
		LearnMode::poll();
		SmartCoachWebServer::instance().handleClient();
	}
}

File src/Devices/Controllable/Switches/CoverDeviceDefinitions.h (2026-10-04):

/*
#include "RVConstants.h"
#ifdef HOME_KIT_2
#ifndef AWNING_DEFINITIONS_H
#define AWNING_DEFINITIONS_H


#include "Arduino.h"


enum class CoverKind : uint8_t {Awning = 0, Shade = 1};
enum class CoverMotion : uint8_t { Stopped = 0x00, Opening = 0x01, Closing = 0x02 };

constexpr uint8_t AWNING_MAX_PERCENT = 100;
constexpr uint8_t AWNING_MIN_PERCENT = 0;
constexpr uint8_t AWNING_STEP = 5;
constexpr float_t AWNING_PERCENT_PRECISION = 0.5; // this is the value returned when no data is available
constexpr uint8_t AWNING_MAX_VALUE = 200; // 200 * 0.5 = 100%
constexpr uint8_t AWNING_PCT_FUDGE_FACTOR = 1;

constexpr uint8_t DOOR_AWNING = 1;
constexpr const char* DOOR_AWNING_NAME = "Door Awning";
constexpr uint8_t FRONT_AWNING = 2;
constexpr const char* FRONT_AWNING_NAME = "Front Awning";
constexpr uint8_t BACK_AWNING = 3;
constexpr const char* BACK_AWNING_NAME = "Back Awning";


constexpr float    DOOR_AWNING_EXTEND_CYCLE_TIME_SEC    = 15000.0F; // time to fully extend door awning 14 seconds
constexpr float    DOOR_AWNING_RETRACT_CYCLE_TIME_SEC   = 15000.0F; // time to fully retract door awning 14 seconds
constexpr float    FRONT_AWNING_EXTEND_CYCLE_TIME_SEC   = 44000.0F; // time to fully extend front awning 44 seconds
constexpr float    FRONT_AWNING_RETRACT_CYCLE_TIME_SEC  = 46000.0F; // time to fully retract front awning 46 seconds
constexpr float    BACK_AWNING_EXTEND_CYCLE_TIME_SEC    = 44000.0F; // time to fully extend back awning 44 seconds
constexpr float    BACK_AWNING_RETRACT_CYCLE_TIME_SEC   = 46000.0F; // time to fully retract back awning 46 seconds
constexpr uint8_t  AWNING_FULLY_RETRACTED_PCT           = 100;        // fully retracted awning percentage
constexpr uint8_t  AWNING_FULLY_EXTENDED_PCT            = 0;      // fully extended awning percentage
constexpr uint8_t  AWNING_STEP_PCT                      = 1;        // awning step percentage
constexpr float    DEFAULT_EXTEND_TIME_SEC              = FRONT_AWNING_EXTEND_CYCLE_TIME_SEC;
constexpr float    DEFAULT_RETRACT_TIME_SEC             = FRONT_AWNING_RETRACT_CYCLE_TIME_SEC;

typedef enum {
    // all indeces are zero based
    AWNING_INSTANCE_INDEX                     = 0,
    // STATUS
    AWNING_STATUS_MOTION_INDEX                = 1, 
    AWNING_STATUS_POSITION_INDEX              = 2,
    AWNING_STATUS_TRAVEL_LOCK_INDEX           = 3,
    AWNING_STATUS_PARK_INDEX                  = 4,
    AWNING_STATUS_LIGHT_INDEX                 = 5,
    AWNING_STATUS_LIGHT_DIM_INDEX             = 6,
    AWNING_STATUS_2ND_LIGNT_INDEX             = 7,
    // COMMAND
    AWNING_COMMAND_LOCK_INDEX                 = 1,
    AWNING_COMMAND_DIRECTION_INDEX            = 2,
    AWNING_COMMAND_POSITION_INDEX             = 3,
    AWNING_COMMAND_MOTION_INDEX               = 4,
    AWNING_COMMAND_LIGHT_INDEX                = 6,
    AWNING_COMMAND_2ND_LIGHT_INDEX            = 7,
    // STATUS 2
    AWNING_STATUS_2_MOTION_SENSITIVITY_INDEX  = 1,
    AWNING_STATUS_2_CALBRATION_INDEX          = 2,
    AWNING_STATUS_2_EXTEND_LOCKOUT_INDEX      = 3,
    AWNING_STATUS_2_RETRACT_LOCKOUT_INDEX     = 4,
    AWNING_STATUS_2_INPUT_STATE_INDEX         = 5,
    // COMMAND 2
    AWNING_COMMAND_2_MOTION_SENSITIVITY_INDEX = 1,
    AWNING_COMMAND_2_CALBRATION_INDEX         = 2,
    AWNING_COMMAND_2_EXTEND_LOCKOUT_INDEX     = 3,
    AWNING_COMMAND_2_RETRACT_LOCKOUT_INDEX    = 4,
    AWNING_COMMAND_2_INPUT_STATE_INDEX        = 5

} AWNING_INDECES;

typedef enum {
    INTEGRATED_LIGHT_INDEX = AWNING_COMMAND_LOCK_INDEX,
    INTEGRATED_LIGHT_MASK      = 0x30,   // 0011 0000 
    INTEGRATED_LIGHT_MASK_COMP = 0xcf,   // 1100 1111
    INTEGRATED_LIGHT_ON        = 0x10,   // 0001 0000
    INTEGRATED_LIGHT_OFF       = 0x00    // 0000 0000
} INTEGRATED_LIGHT;

// AWNING Command definitions
typedef enum {
    AWNING_STOP_COMMAND       = 0x00,
    AWNING_EXTEND_COMMAND     = 0x01,
    AWNING_RETRACT_COMMAND    = 0x02
} AWNING_COMMAND_DIRECTION;

// AWNING Command 2 definitions

// Awning Status definitions
typedef enum {
    NO_MOTION            = 0x00, // CoverMotion::Stopped, // 0000 0000
    EXTENDING            = 0x01, // CoverMotion::Opening, // 0000 0001
    RETRACTING           = 0x02  // CoverMotion::Closing  // 0000 0010
}AWNING_MOTION;

constexpr uint8_t AWNING_LIGHT_MAX_PERCXENT = MAX_RVC_PERCENT * RVC_PERCENT_PRECISION;
typedef enum {
    AWNING_LIGHT_ON          = AWNING_LIGHT_MAX_PERCXENT, 
    AWNING_LIGHT_OFF         = 0x00 
} AWNING_LIGHT_STATUS;

// Awning Status 2 definitions
constexpr float homeKitShadeOpenValue = 100.0;
constexpr float homeKitShadeClosedValue = 0.0;
typedef uint16_t   ShadeState;
constexpr uint16_t shadeStateClosing = 1 << 3;
constexpr uint16_t shadeStateOpening = 1 << 4;
constexpr uint16_t shadeStateMoving = shadeStateClosing | shadeStateOpening;

constexpr uint16_t shadeStateUserAction = 1 < 6;
constexpr uint16_t shadeStateHomeKitAction = 1 << 7;
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

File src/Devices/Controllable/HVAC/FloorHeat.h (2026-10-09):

#include "RVConstants.h"

#ifndef FLOOR_HEAT_H
#define FLOOR_HEAT_H 
#include "GenericDevice.h"
#include "FloorHeatDefinitions.h"
#include "debug.h"

class FloorHeat : public GenericDevice {
    private:
        uint8_t*        commandData;
        uint8_t*        getCommandData(void) const { return commandData; } 

        friend class FloorHeatView;

        bool isTurnedOn(void) const {
            bool result = false;
            uint8_t* data = getCurrentData();
            if (data != nullptr) {
                uint8_t status = data[FLOOR_HEAT_GEN_STATUS_INDEX];
                constexpr uint8_t onMask = static_cast<uint8_t>(FLOOR_HEAT_GEN_STATUS_HEATING_ON) |
                                           static_cast<uint8_t>(FLOOR_HEAT_ELEMENT_STATUS_ON);
                if ((status & onMask) == onMask) {
                    result = true;
                    //RV_PRINTF("FloorHeat::isTurnedOn - heating is ON\n");
                    // keep it simple and make sure that only these bits are on
                    // data[FLOOR_HEAT_GEN_STATUS_INDEX] = FLOOR_HEAT_GEN_STATUS_HEATING_ON | FLOOR_HEAT_ELEMENT_STATUS_ON;
                }
            }
            return result;
        }   

        void turnFloorHeatOff(void) {
            uint8_t* cData = getCommandData();
            if (cData != nullptr) {
                cData[FLOOR_HEAT_GEN_STATUS_INDEX] = FLOOR_HEAT_COMMAND_OFF;
                cData[FLOOR_HEAT_COMMAND_SET_TEMPERATURE_MSB_INDEX] = 0x00;
                cData[FLOOR_HEAT_COMMAND_SET_TEMPERATURE_LSB_INDEX] = 0x00;
                executeCommand(FLOOR_HEAT_COMMAND, cData);
            }
        }

        void turnFloorHeatOn(float_t temperatureC) {
            uint8_t* cData = getCommandData();
            if (cData != nullptr) {
                // RV_PRINTF("FloorHeat::turnFloorHeatOn for index = %d - setting temperature to %f C\n",index(), temperatureC);
                uint16_t tempValue = convFromTempC(static_cast<double>(temperatureC));
                // RV_PRINTF("FloorHeat::turnFloorHeatOn for index = %d - converted temperature to raw int value %d\n",index(), tempValue);
                // cData[FLOOR_HEAT_GEN_STATUS_INDEX] = FLOOR_HEAT_GEN_STATUS_HEATING_ON | FLOOR_HEAT_ELEMENT_STATUS_ON;
                cData[FLOOR_HEAT_GEN_STATUS_INDEX] = FLOOR_HEAT_COMMAND_ON;

                setLilEndian(cData,
                             FLOOR_HEAT_COMMAND_SET_TEMPERATURE_MSB_INDEX, FLOOR_HEAT_COMMAND_SET_TEMPERATURE_LSB_INDEX, 
                             tempValue);
                // RV_PRINTF("FloorHeat::turnFloorHeatOn for index = %d - on/off = %x, command data msb: %02x, lsb: %02x\n", 
                //    index(), cData[FLOOR_HEAT_GEN_STATUS_INDEX], cData[FLOOR_HEAT_COMMAND_SET_TEMPERATURE_MSB_INDEX], cData[FLOOR_HEAT_COMMAND_SET_TEMPERATURE_LSB_INDEX]);
                executeCommand(FLOOR_HEAT_COMMAND, cData);
            }
        }

        void storeFloorHeat(void) {
            uint8_t* cData = getCommandData();
            if (cData != nullptr) {
                cData[FLOOR_HEAT_GEN_STATUS_INDEX] = FLOOR_HEAT_COMMAND_ON;
                uint16_t tempValue = convFromTempC(static_cast<double>(FLOOR_HEAT_TEMP_STORE));
                setLilEndian(cData,
                             FLOOR_HEAT_COMMAND_SET_TEMPERATURE_MSB_INDEX, FLOOR_HEAT_COMMAND_SET_TEMPERATURE_LSB_INDEX, 
                             tempValue);
                executeCommand(FLOOR_HEAT_COMMAND, cData);
                // cData[FLOOR_HEAT_COMMAND_SET_TEMPERATURE_MSB_INDEX] = 0x00;
                // cData[FLOOR_HEAT_COMMAND_SET_TEMPERATURE_LSB_INDEX] = 0x00;
            }
        }   

        float_t currentFloorHeatTemperature(void) const {
            float_t result = INVALID_TEMPERATURE; // invalid temperature
            uint8_t* data = getCurrentData();
            if (data != nullptr) {
                uint8_t msb = data[FLOOR_HEAT_STATUS_MEASURED_TEMPERATURE_MSB_INDEX];
                uint8_t lsb = data[FLOOR_HEAT_STATUS_MEASURED_TEMPERATURE_LSB_INDEX];
                uint16_t tempValue = getLilEndian(msb, lsb);
                if (tempValue != BAD_UINT16_DATA) {
                    float_t temperatureC = convToTempC(tempValue);
                    if (temperatureC >= -50.0F && temperatureC <= 100.0F) result = temperatureC;
                }
            }
            return result;
        }

        float_t currentFloorHeatSetting(void) const {
            float_t result = INVALID_TEMPERATURE; // invalid temperature
            uint8_t* data = getCurrentData();
            if (data != nullptr) {
                uint8_t msb = data[FLOOR_HEAT_STATUS_SET_TEMPERATURE_MSB_INDEX];
                uint8_t lsb = data[FLOOR_HEAT_STATUS_SET_TEMPERATURE_LSB_INDEX];
                uint16_t tempValue = getLilEndian(msb, lsb);
                if (tempValue != BAD_UINT16_DATA) {
                    float_t temperatureC = convToTempC(tempValue);
                    if (temperatureC >= -50.0F && temperatureC <= 100.0F) result = temperatureC;
                }
            }
            return result;
        }

    protected:
        virtual CAN_frame_t* buildCommand(RVC_DGN dgn);
        virtual void setData(RVC_DGN dgn, uint8_t* data) {
            if (data != nullptr) {
                uint8_t* rawData = getCurrentData();
                uint8_t* cData = getCommandData();
                if ((rawData != nullptr) && (cData != nullptr))// set the current data to the new data
                switch (dgn) {

                    case FLOOR_HEAT_COMMAND:
                        // RV_PRINTF("FloorHeat::setData: FLOOR_HEAT_COMMAND received\n");
                        for (uint8_t i = 1; i < 8; i++) {
                            cData[i] = data[i]; // copy the command data
                        }
                        break;
                    case FLOOR_HEAT_STATUS:
                        // RV_PRINTF("FloorHeat::setData: FLOOR_HEAT STATUS received for index %d: ", index());
                        for (uint8_t i = 1; i < 8; i++) {
                            rawData[i] = data[i]; // copy the status data
                            // RV_PRINTF(" - byte %d: %02x", i, data[i]);
                        }
                        // RV_PRINTF("\n");
                        break;
                    default:
                        // do nothing
                        break;
                }
            }
        }
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

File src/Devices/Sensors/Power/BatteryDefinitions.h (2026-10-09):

#include "RVConstants.h"
//#include "debug.h"
#ifndef BATTERY_DEFINITIONS_H
#define BATTERY_DEFINITIONS_H
#include "Arduino.h"

// Battery monitoring is performed by reading the DGN of the DC_SOURCE_STATUS_1, 2, 3, and 4, since the raw data from these packets are considerably different, 
// we will add 3 more data vectors. Thus setData will be more complex and based on the DGN. There are 12 DC_SOURCE_STATUS, but Newmar only seems to use the first
// few, so I limited the count to just the first 4.
typedef enum {
    DC_SOURCE_INSTANCE_INDEX             = 0, // all DC_SOURCE_STATUS
    DC_SOURCE_PRIORITY_INDEX             = 1, // all DC_SOURCE_STAtua
    DC_SOURCE_VOLTAGE_MSB_INDEX          = 2, // from DC_SOURCE_STATUS_1
    DC_SOURCE_VOLTAGE_LSB_INDEX          = 3, // from DC_SOURCE_STATUS_1
    DC_SOURCE_CURRENT_MSB_1_INDEX        = 4, // from DC_SOURCE_STATUS_1
    DC_SOURCE_CURRENT_MSB_2_INDEX        = 5, // from DC_SOURCE_STATUS_1
    DC_SOURCE_CURRENT_LSB_1_INDEX        = 6, // from DC_SOURCE_STATUS_1
    DC_SOURCE_CURRENT_LSB_2_INDEX        = 7, // from DC_SOURCE_STATUS_1
    DC_SOURCE_TEMPERATURE_MSB_INDEX      = 2, // from DC_SOURCE_STATUS_2
    DC_SOURCE_TEMPERATURE_LSB_INDEX      = 3, // from DC_SOURCE_STATUS_2
    DC_SOURCE_STATE_OF_CHARGE_INDEX      = 4, // from DC_SOURCE_STATUS_2
    DC_SOURCE_TIME_REMAINING_MSB_INDEX   = 5, // from DC_SOURCE_STATUS_2
    DC_SOURCE_TIME_REMAINING_LSB_INDEX   = 6, // from DC_SOURCE_STATUS_2
    DC_SOURCE_TIME_INTERPRETATION        = 7, // from DC_SOURCE_STATUS_2
    DC_SOURCE_HEALTH_STATE_INDEX         = 2, // from DC_SOURCE_STATUS_3
    DC_SOURCE_CAP_REMAINS_MSB_INDEX      = 3, // from DC_SOURCE_STATUS_3
    DC_SOURCE_CAP_REMAINS_LSB_INDEX      = 4, // from DC_SOURCE_STATUS_3
    DC_SOURCE_RELATIVE_CAP_INDEX         = 5, // from DC_SOURCE_STATUS_3
    DC_SOURCE_AC_RIPPLE_MSB_INDEX        = 6, // from DC_SOURCE_STATUS_3
    DC_SOURCE_AC_RIPPLE_LSB_INDEX        = 7, // from DC_SOURCE_STATUS_3
    DC_SOURCE_DESORED_CHARGE_STATE_INDEX = 2, // from DC_SOURCE_STATUS_4
    DC_SOURCE_DESIRED_VOLT_MSB_INDEX     = 3, // from DC_SOURCE_STATUS_4
    DC_SOURCE_DESIRED_VOLT_LSB_INDEX     = 4, // from DC_SOURCE_STATUS_4
    DC_SOURCE_DESIRED_AMP_MSB_INDEX      = 5, // from DC_SOURCE_STATUS_4
    DC_SOURCE_DESIRED_AMP_LSB_INDEX      = 6, // from DC_SOURCE_STATUS_4
    DC_SOURCE_BATTERY_TYPE_INDEX         = 7, // from DC_SOURCE_STATUS_4
    DC_SOURCE_FAULT_INDEX                = 0xf
} DC_SOURCE_DATA_INDECES;

typedef enum {
    INVALID_SOURCE            = 0,
    MAIN_HOUSE_BATTERY        = 1,
    CHASSIS_START_BATTERY     = 2,
    SECONDARY_HOUSE_BATTERY   = 3,
    GENERATOR_STARTER_BATTERY = 4,
    MFG_OTHER                 
} DC_SOURCE_INSTANCE_DEFINITION;

typedef enum {
    BATTERY_SOC_BMS_DEVICE = 120,
    INVERTER_CHARGER       = 100,
    CHARGER                = 80,
    INVERTER               = 60,
    MULTI_METER            = 40,
    VOLT_METER             = 20,
    NO_PRIORITY_ALWAYS_RPT = 0
} DC_SOURCE_PRIORITY_DEFINTION;

typedef enum {
    UNDEFINED_CHARGE_STATE = 0,
    DO_NOT_CHARGE_STATE    = 1,
    BULK_CHARGE_STATE      = 2,
    ABSORPTION_STATE       = 3,
    OVERCHARGE_STATE       = 4,
    EQUALIZE_STATE         = 5,
    FLOAT_STATE            = 6,
    CONSTANT_VOLTAGE_STATE = 7
} CHARGE_STATE;

typedef enum {
    FLOODED_BATTERY = 0,
    GEL_BATTERY     = 1,
    AGM_BATTERY     = 2,
    LITHIUM_BATTERY = 3,
    VENDOR_DEFINED
} BATTERY_TYPE;

const float_t VDC_PRECISION = 0.05;
const float_t ADC_PRECISION = 0.001;
const uint16_t VDC_RAW_MAX = 64250;
const float_t VDC_MAX = 3212.5f;
const uint32_t ADC_MAX = 2221082;
const uint16_t VDC_OFFSET = 0;
const float_t ADC_OFFSET = 2000000;
const uint32_t ADC_ZERO = 0x77359400;
const uint16_t INVALID_AMP_HOURS = 0xffffu;
const uint16_t INVALID_RMS_RIPPLE = 0xffffu;
/*
const float_t VDC_UPPER_LIMIT = 15.0f;
const float_t VDC_LOWER_LIMIT = 0.0f;
const float_t VDC_NOMINAL_VALUE = 12.0f;
const float_t ADC_UPPER_LIMIT = 50.0f;
const float_t ADC_LOWER_LIMIT = -50.0f;
const float_t ADC_NOMINAL_VALUE = 0.0f;
const float_t VDC_RIPPLE_UPPER_LIMIT = 2500.0f;
const float_t VDC_RIPPLE_LOWER_LIMIT = 0.0f;
const float_t VDC_RIPPLE_NOMINAL_VALUE = 0.0f;
*/

#endif

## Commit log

2025-08-02 Add files via upload
    Forked branch from rubillos, he did all the original heavy lifting. I refactored code into an object oriented framework using MVC, where the model is the coach devices and sensors via the RVC-Bus,. T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
2025-08-02 Delete src/Devices/Controllable/Switches/Awning.h
    empty
2025-08-04 Update DeviceFactory.cpp
    refactored some code, removed unnecessary ideas in original design
2025-08-04 Update ChassisMobility.h
    rm grp and dgns
2025-08-05 Update DeviceFactory.cpp
    updated to clean up a bit
    removed dgns, groups
2025-08-05 Update ChassisMobility.h
    cleaned up a bit
    removed dgns and group
2025-08-05 Update Thermostat.h
    updated to cleanup a bit, fix the hot and cold temps,
    [Thermostat.h]
2025-08-05 Update ChassisMobility.h
    copy and paste dropped the .h #ifndef and #define
2026-07-08 added, tested, and used Awnings now.
    modified: Base/RVConstants.h
    modified: Devices/Controllable/Switches/Awning.cpp
    modified: Devices/Controllable/Switches/Awning.h
    modified: Devices/Controllable/Switches/AwningDefinitions.h
    modified: Devices/Controllable/Switches/AwningView.cpp
    modified: Devices/Controllable/Switches/AwningView.h
    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
2026-09-05 fixed the file to remove hard paths
    [main.cpp]
2026-09-06 fixed thermostat level increments, fixed tanks configured name and removed batterly level, fixed battery issues with calculations and lil endian, removed unnecessary printfs, added Shades
    [Battery.h, BatteryDefinitions.h, HVAC_defintions.h]
2026-09-06 fixed rmsRipple on Battery and removed delete[] in ThermostatView
    [Battery.h, BatteryDefinitions.h]
2026-09-07 Fix bit issues in power devices, including ATS, Battery and Generator that would incorrectly identify line
    [Battery.h]
2026-09-07 Fixed dual leg issues on power
2026-09-08 corrected design for Inverter
    [RVConstants.h]
2026-10-03 Major revision, this puts all of the code under one roof in an ESP32-S3 board. It also adds a Captive Portal to capture the SSID and Password. Finally, it reads json files for its configuration
2026-10-03 Major revision, this puts all of the co de under one roof in an ESP32-S3 board. It also adds a Captive Portal to capture the SSID and Password. Finally, it reads json files for its configuration" [ma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
2026-10-03 v2.1.0: fix deprecation warnings, virtual destructors, explicit move ops, view string leaks
    [Battery.h, FloorHeat.h, WaterPump.h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]
2026-10-03 Remove obsolete HOME_KIT_1 and HOME_KIT_2 guards
    Enable both device groups unconditionally for the unified ESP32-S3 firmware. Remove active feature definitions and their matching conditional wrappers while preserving header guards and historical co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
2026-10-04 Harden learning persistence and stable AID recovery
    Preserve owner metadata and quiet devices during re-learning, reject incomplete writes, retain recoverable completion state, and restore backups only when cancelling an active run. Reserve fresh-unit chassis IDs and persist an AID high-water mark to prevent automatic reuse after deletion.
    Add 34 host regression tests with filesystem and NVS fault injection. Refactor web/email handling toward Single Entry Single Exit and add disabled FUTURE diagnostics/email scaffolds. Normal firmware uploaded; user confirmed clean HomeKit validation and retained rooms/readings. FUTURE runtime behavior and physical power-loss testing remain outstanding.
2026-10-04 Add pending device review and discovery
2026-10-04 Enable owner-consented Gmail reporting
    Add the HTTPS Gmail relay, per-coach token storage, validated owner recipients, current-inventory fallback, and explicit outbox delivery. Promote email into normal Release while preserving runtime co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
    Validated with 66 host checks, 10 Apps Script relay tests, successful live owner-only Gmail delivery, and successful Release and DiagnosticsBeta builds. No firmware upload or filesystem update is par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
2026-10-04 Enable passive diagnostics by default
    Compile bounded passive bus/device diagnostics in normal Release, add the DiagnosticsBeta compatibility alias, and expose a firmware-served diagnostics view with link injection for older LittleFS por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
    Validated 70 host checks, diagnostics-only route and streaming regressions, Release and DiagnosticsBeta builds, and live diagnostics page/link after firmware-only upload. HomeSpan remains clean.
2026-10-04 Harden diagnostics memory and model ownership
    Delete unsafe GenericDevice and derived copy operations, make LittleFS coach loading non-formatting, and centralize view ownership through SpanView(model). Bound generated JSON and root portal buffer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
    Validated with 72 host checks and successful Release/DiagnosticsBeta builds. The currently deployed DiagnosticsBeta passed HomeSpan validation; this follow-up was build-tested but not uploaded.
2026-10-05 Add files via upload
    Web Portal and sample EVE Home Devices, Scenes and Rules
